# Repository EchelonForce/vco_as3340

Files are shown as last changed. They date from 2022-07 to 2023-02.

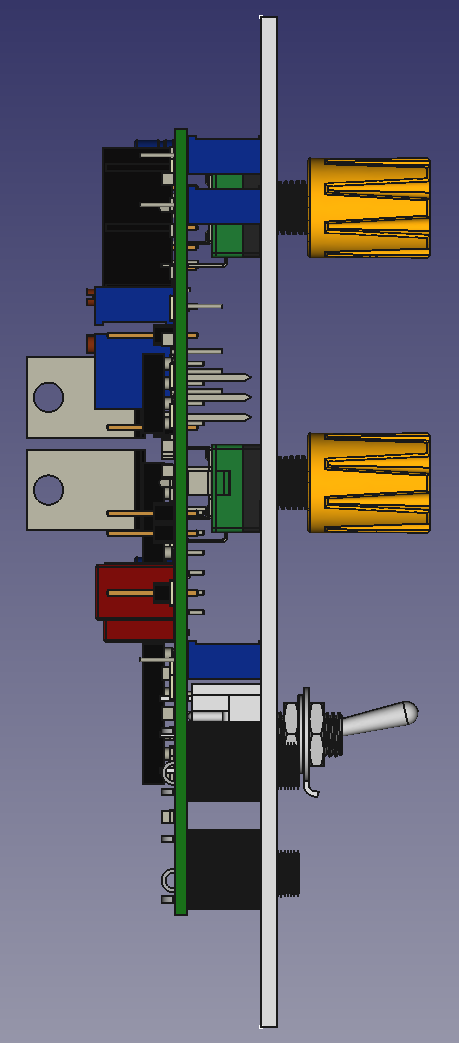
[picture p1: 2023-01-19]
front_panel_v2.1/render3.png

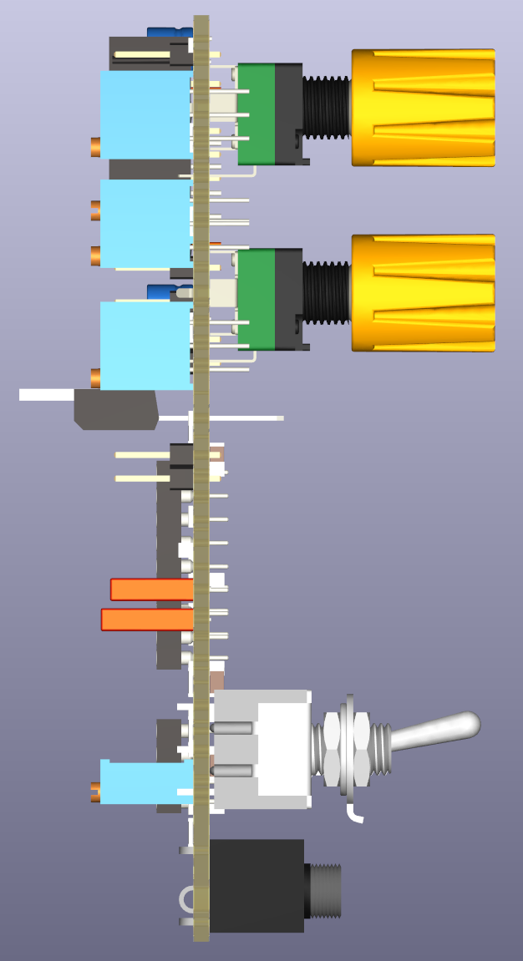
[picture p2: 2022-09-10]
vco_as3340_v1/vco_as3340_v1_render3.png

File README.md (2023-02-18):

# Eurorack VCO AS3340

This is a design for a eurorack VCO using the AS3340 VCO chip.

Full writeup here: https://www.robotdialogs.com/2023/02/eurorack-vco-module-as3340-v21.html
v1. writeup: https://www.robotdialogs.com/2022/09/eurorack-vco-module-as3340.html

This work is licensed under a Creative Commons Attribution-NonCommercial-ShareAlike 4.0 International License. https://creativecommons.org/licenses/by-nc-sa/4.0/

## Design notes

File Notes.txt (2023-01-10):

Issues on v1
 - When making the front panel drawings I noticed the fine tune pot and PWM pot are not equally spaced from the center line. Also the jacks centers are not equidistant from the sides making front panel layout awkward. I made the whole PCB off center relative to the front panel to mitigate this.

 - Fought the output of the pulse wave a lot. There was a lot of ringing on the falling edge. I found some info online https://lookmumnocomputer.discourse.group/t/glitches-or-ringing-on-the-pulse-output-of-the-as3340-and-cem3340/752/5
that suggests using a 10M between the PWM an Pulse pins. I tried that and a few other values but still had issues. I also tried a few small cap values trying to filter the pulse output. Eventually I probed the -5V supply at the chip and found significant ripple in that supply. When I removed the chip (no load) the ripple went away, so I patched in more capacitance at the JP3 jumper (10uF polarized) and that cleaned up the wave considerably. There was still some ring in the pulse output after the buffer that wasn't there pre-buffer (see notes later about scope probe). I removed R6 to help with that. R6 was meant to be a pulldown for the buffer input that I've used in other designs but here it interfered with the R7/R8 voltage divider causing lower than expected output.

- After building 4 of these (intending to test different caps) I have had issues with tuning accross all of them so I pulled them out of the rack and started debugging that. First I started by retrimming everything. I suspect I was impatient after building them because all of them needed adjustment. I powered them all on togeth and let them sit about an hour and then trimmed RZ_TEMP1 again and waited another half hour or so. Then went about the tuning by shorting JP4 and tuning to C6. I found while doing this that tuning one vco against another was easier than tuning to 1046.5 on my scope. The wave forms slide in and out of phase visually on screen and I can get them very close by bringing the slide to a stop but it's fiddely, they never really stop for long. I finished with unshorting and refinding C6 with the 5V CV and C1 with the 0V CV (again tuning with visually helped).

- After all that I let the run for a while and came back to check the pulse wave again and on one it was pretty ringy on the falling edge but only below 5V CV... so I googled again and found this thread
https://modwiggler.com/forum/viewtopic.php?t=231130
That led me to retry a 10M 'hysteresis' resistance between pins 4 and 5, which again didn't work. Strangely if I probed from pin 4 directly the output would be quite a bit better, but a pretty long flank on the falling edge, I guess the scope probe impedance/capacitance was effecting it a lot...On the same thread others mentioned a pull down cap on pin 4 and this improved things significantly. I landed on 100pF after trying large and smaller common values. Unlike the smoothing cap added to the -5V rail earlier, I don't have a nice place to rework this cap to the boards. 

So now there's finally a pretty clean pulse across the 0V-10V range

Current state: 2022-08-23 - See phone photo
 - R10 is 47k
 - 100pF across R10
 - R9 short
 - JP3 10uF polarized cap from -5 to -12 rail. 
 - JP2 short
 - R5 short
 - R6 DNU
 - JP1 short
 - Unit 1 & 2 - red caps
 - Unit 3 - white cap
 - Unit 4 - poly cap
 - R21 & R23 are 5.1k
 - RZ1 18k not 13k

Some other things to investigate.
 - try running on batteries to see if it cleans up frequency meandering? measure first.
 - buy and try higher precision resistors R30, R2,
 - I haven't messed with high freq. track at all yet.
 - Need to do more thorough look at tracking in general from 0-10V.
 - Fine tune knob has a little too much influence on tune, several semi tones... reduce?
   - Increase R3 or reduce range of RFINE_TUNE1
 - Try 5.6k on R21,R23 to reduce component count.

2022-08-28 - Testing Notes
Did a bunch of testing with the frequency counter. 
Completely retuned all four DUTs with frequency counter and mV scale for temp adjust step 1.
The tracking from 0v to 5V looked pretty good using a bench supply for CV and multimeter with mV accuracy. Frequency counter struggled a bit at some frequencies, compared against oscilliscope at lower frequencies.
  Procedure was:
   Powered on for 1hr or more to warm up.
   Readjusted temp1 w/ mV range on multimeter, drifts a bit, got it under a mV.
   Short J4 and get 1046.5 with ref pitch.
   Set Fine Tune knob to center.
   Set Freq knob to 0, full CCW.
   Input CV 5.000V+-0.001
   Use Refind C6 to get 1046.5, this was trickier than with F4 shorted.
   Input CV 0.000V+-0.001
   Use scale adjust to get 32.70+/-0.01 Hz 
   Checked tracking.

 V    Unit   
        1      2       3        4    Ideal
0V    32.7    32.7    32.7    32.7   32.7
1V    65.45   64.9    66.0    66.0   65.41
2V   130.9   130.2   130.7   130.6   130.81
3V   261.9   260.8   261.8   261.4   261.63
4V   523.3   521.6   523.4   522.5   523.25
5V   1047    1045    1049    1046    1046.5

So nearly all within a 1Hz of ideal. 

At this point I checked the weird result the tuner gives me at 1046 with a signal from the frequency gen. I was weird there too and I will investigate that later.

Then I went into trying the DUTs with the midi cv. Unfortunately that also has and issue so the impedance of the oscillators effect it's output. Details in that other note sheet...ugh. 

After some fiddling with the midicv, I thought I had it generating accurate voltages. Unfortunately because the oscillators were tuned with a strong voltage source they didn't behave. All of them need to be offset with the knob :( I want to avoid that, but I guess I have to tune them with the midi source instead??? Kind of confused about this. They seem to work okay with manual tune.

Maybe I just need to redo the circuit and accept the harder tuning method...or maybe is psu voltage differences.
Starting to think a digital oscillator would be so much easier.

2022-09-04
Did some more rigid testing of the AI011 and DUT2. See testing folder notes. 

Schematic Changes v1 to v2:
 - R10 = 47k
 - R9 = 0ohm 
 - New C1 100pF across R10 and R9
 - New C15 10uF polarized cap from -5 to GND. 
 - R6 DNU
 - R21 & R23 changed to 5.1k 
 - RZ1 changed to 18k
 - R26 changed to 100k and new R31 is 100k.
 - New  R32 for 'hysteresis' between PWM and Pulse.
 - Separated grounds on Linear FM and Scale Adj. Circuits for clarity.
 - Added another TL072 (U6) and supporting circuits.
    - This is intended to supply two reference voltages from the 5V source.
    - The idea is to provide Soft Sync (pin 9) with a stable voltage of 1/3*Supply, which is something like 11.3/3.
    - The other REF_PITCH1 is for the Linear FM circuit. Some resistors probably aren't right for this yet, replaced original ref_pitch with this.
  Moved outputs to a tl074 to save some space.
  Removed jp1,2,3 and extra vee stuff, just going to use -5V ref.
  Added second frequency CV jack.

Other 
 - During assembly, short J1 and J2

Sim of virtual ground summing node on CVs
https://tinyurl.com/29nqo2se

https://www.eddybergman.com/2020/01/synthesizer-build-part-18-really-good.html

---------------------------------------------------------------------------------
Issues on v2 PCB:
 - VEE net isn't connected to -5V so the scale adjust circuit isn't powered. Rework short from C10 to RT1.
 - 10pF cap needed on Sawtooth first stage opamp. There was ring in this on the falling edge and this cap helped. (between U4's pins 8/9)
 - Rr1 was changed to 220k from 330k.
 - R4, R33 and R34 should be 100k.
 - C19 should be DNU, it caused oscillation on REF_VOLT_1.
 - Add 10pF on U4B (between pins 6/7) for rising edge of pulse.
 - Add resistors for PWM pot so it's range is limited. (also do fine tune if there's room).
 - Add cal frequencies on silkscreen if there's room.
 - Change supply into REFIND_C6, from 12V to REF_PITCH_1.
 - Change R21 to 10k
 - Change R23 to 0Ohm
 - Change R8 to 110k, lowers pulse out peak to peak.
 
Issues on v2 Front Panel
 - Tried to have holes for the trim pots that are technically on the back of the PCB so they could be mounted on the front, but the holes in the panel are oriented for when the pots are on the back. Need to move them.
 - Trim pot holes could be smaller.
 - Saw wave has rising edge, but it should be falling (rising slope).

Test Notes 2022-12-26:
 - Assembled 2 PCBs.
 - Checked voltage rails +/- 12V, +/- 5V
 - Before adding the AS3340, set the REF_VOLT_1 to 1/3 Vcc = 3.75V
    - I checked REF_VOLT_1 with multimeter (TP3) but that hid the oscillations (almost full peak to peak). Eventually I figure that out with a scope and removed C19 and changed REF_VOLT_1 op-amp resistors for non-unity gain.
 - Add the AS3340.
 - Tried an output and there was no frequency change when the knobs were used...
 - Tried cal step 1 (temp adjust) but the diff between TP1/2 was exactly 0.
 - Debugged this until I figured out the missing VEE net to -5V connection. Fixed with short between C10 and RT1.
 - Checked the other outputs. Sawtooth had bad ring in it the AS3340 output was clean, so I added a 10pF on the first stage opamp feedback which improved it considerably.
 - Did Cal step 1, okay.
 - During Cal step 2 I couldn't get C6 on the output, it was close, so I looked at the new REF_PITCH voltage reference, it was maxing out at ~10V from the opamp, since it can't go any higher I changed Rr1 from 330k to 220k and that was just enough head room. Might need even lower to allow lower input voltages.
 - Checked Fine Tune range. Seems to be +/-2 semi-tones (at 5V on freq CV) which I think is okay.
 - Measured the triangle wave symmetry with scope cursors. Seems perfect at 5V on freq CV. 

Test Notes 2023-01-07:
 - Checked PWM knob range. It goes to 100% Duty too early @ 3.9V. 
  - Need to add a couple resistors inline with the pot to adjust it to the useful range.
 - Recorded some frequency data while adjusting the Vcc from 11.9V up to 12.1V. 
  - The frequency change (starting with 1000Hz at 12V) was 50Hz over the 0.2V range tested. 
    - Also tested a v1.0PCB and the result was similar. This is about 25% per Volt.
  - I think it's due to the REFIND_C6 supply voltage varying.
 - Checked Square wave peak to peak, it's about 11V. And there's a bi of ring on the rising edge.
  - Made R8 = 110k to lower the output closer to 10V.
  - Added a 10pF cap on top of R27 to help the ring. (took photos).
 - Tested the PWM effect on frequency with and without the R32 populated (2.2MOhm and open).
  - No significant difference. Tested 5% increments at a 1000Hz starting point, in both cases, aout 6Hz change over full PWM range.

Test Notes 2023-01-08:
 - Tried to fix the supply voltage into REFIND_C6. cut the 12V trace and wired it to TP4 (REF_PITCH1).
  - Checked REF_PITCH1 with scope after rework to make sure it was stable still.
  - After this tried several Vcc voltages and it's much improved, At 1000Hz @ 12V, 998 @ 12.25V and 1004 @ 11.75V. So about 6Hz over 0.5V. This is about 1.2% per Volt. That's way better than yesterday's test w/o this. Through test REF_PITCH1 was rock solid 9.727V (set from cal steps).

Old Todos:
 - Test CV to freq scaling more throughly.
    - Done.
 - Test freq/pwm shift and try the 'hysteresis' resistor R32.
    - Done.
 - Test with different supply voltages to see if the behavior is better.
    - Done. It's about the same as v1.0 until I reworked REFIND_C6 supply.

 - Tested the HF Track adjustment. At 10V CV the pot couldn't reach an adequate setting for 33488Hz.
 - Decided to measure the voltage (and therefor current) of the HF Track pin. At 10V CV, the HF pin over the 20200k combined resistance, the voltage was 1.331V (also tested other CVs). So there's about 65uA out of the HF pin. Instead of risk a bunch of other issues, swapped the resistors but kept the overall resistance nearly the same.
  - Removed both 5.1k R21/R23. R21 was changed to 10k, R23 was shorted. This put the trim pot in the area need to trim out the tracking error at 10V CV.
  - Re-tested tracking from 0 to 10V CV. All good: https://docs.google.com/spreadsheets/d/1qfa5OgiflcCrpyueND8rxWKN7h0p5OLnycMwUe4vgko/edit?usp=sharing
 - Did all reworks to DUT2 and calibrated it. Seems okay.

Test Notes 2023-01-09:
 - Checked Sync input. Seems okay on hard sync. Requires hard edges like VCO pulse, soft edges don't work. 
    - Switch is not really useful with REF_VOLT and JP5. Added JP1 so that switch can function as a sync enable/disable.
 - Updated PCB and Schematic with all changes in redlined pdf of v2.

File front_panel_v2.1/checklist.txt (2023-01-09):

Kicad:
Open the PCB and export as .step.

FreeCAD:
Copy the template.
Set hp and pcb size in dims spreadsheet
Import .step of pcb from kicad.
Align pcb model with pcb in sketch.
Add holes for jacks etc.
Switch to tech draw workbench. 
Select 'TOP' view of part.
Add part to drawing.
Export as ...no_engraving.dxf (with only part shown, no dims).

Inkcape:
Open .svg template in Inkscape.
Pamel Layer:
  Import the .dxf of the the panel on a layer.
  Change the line stroke to .1 mm
  Scale the .dxf to the nominal panel size, importing screws this up.
  Adjust the page size to the nominal panel size.
Logo Layer:
  Import the Logo\BLEEP_BLOOP_LOGO.svg
  Change the line stroke to .1 mm
Text Layer:
  Add text converting to HersheyText.
   - RobotDialogs
   - Module Name
   - Jack and Pot Labels
   - Voltage Labels
  Change the line stroke to .1 mm
  Remember clearance for nuts/knobs.
Other Layers:
 - As needed.
Save as ...engraving.dxf (AutoCAD DXF R14).

Optional, to double check/render.
FreeCAD:
 - Switch to Draft workbench, turn off the grid (last button on toolbar 'Toggle Draft Grid').
 - Import the engraving dxf.
 - Select all the bits that were imported and select 'Convert draft object to sketch'.
 - Delete the draft objects.
 - Move the sketch +2mm in Z.

Final Checks:
Check text positions, remember clearance for nuts/knobs.
Check that jack/knob names match PCB.
Check for Logo
Check for Voltage labels
Check for missing LED hole.

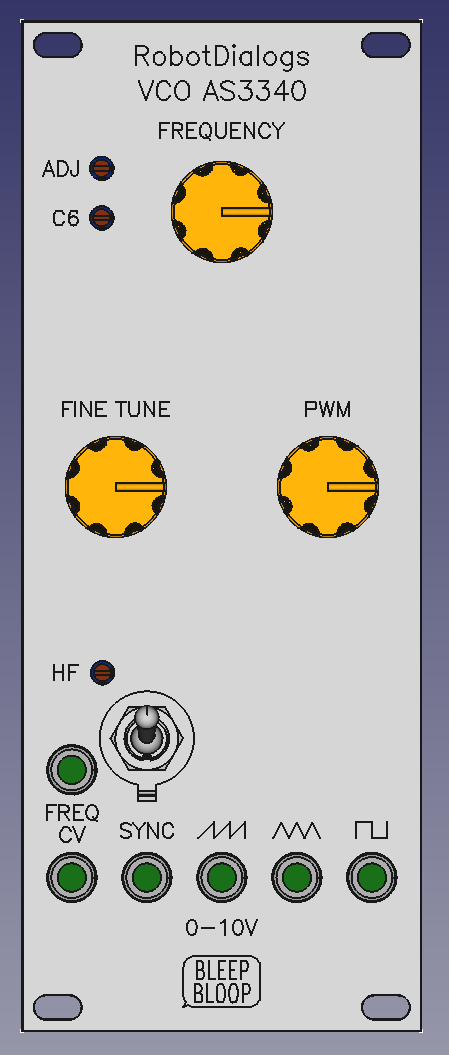
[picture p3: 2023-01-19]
front_panel_v2.1/render1.png

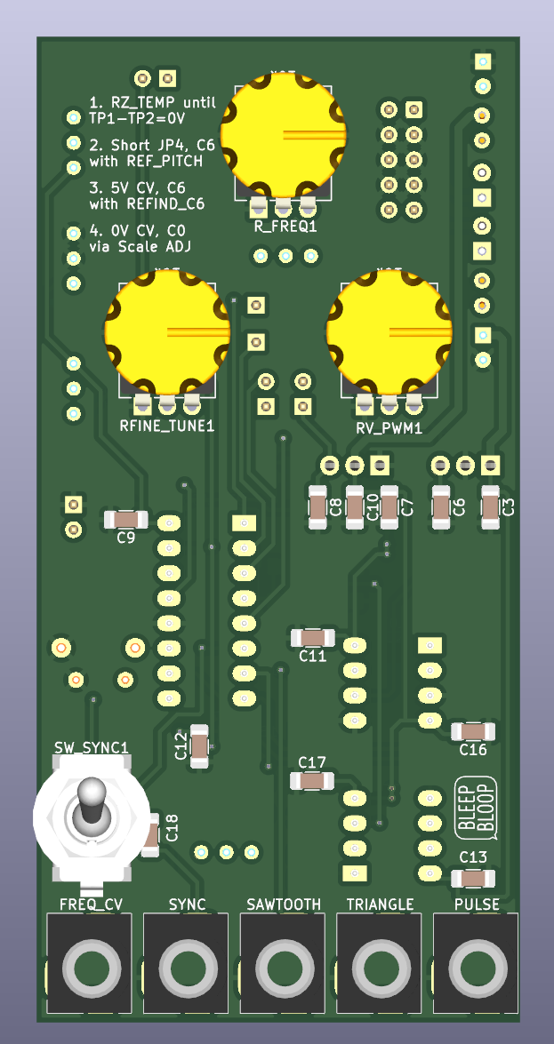
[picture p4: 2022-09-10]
vco_as3340_v1/vco_as3340_v1_render1.png

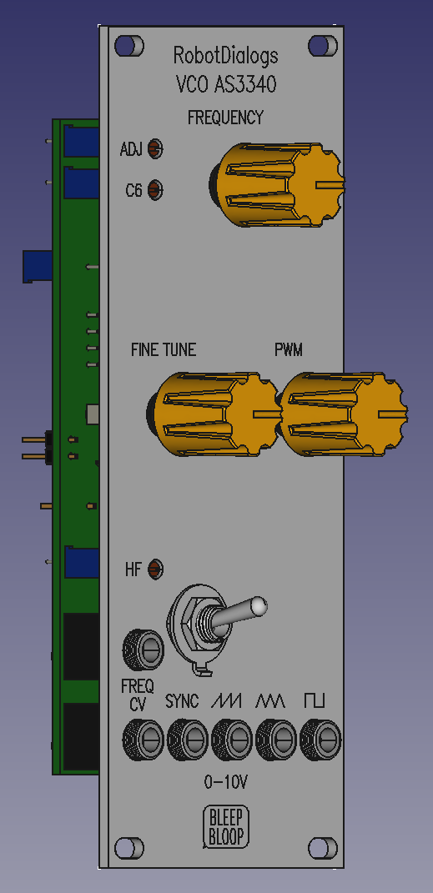
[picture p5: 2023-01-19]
front_panel_v2.1/render2.png

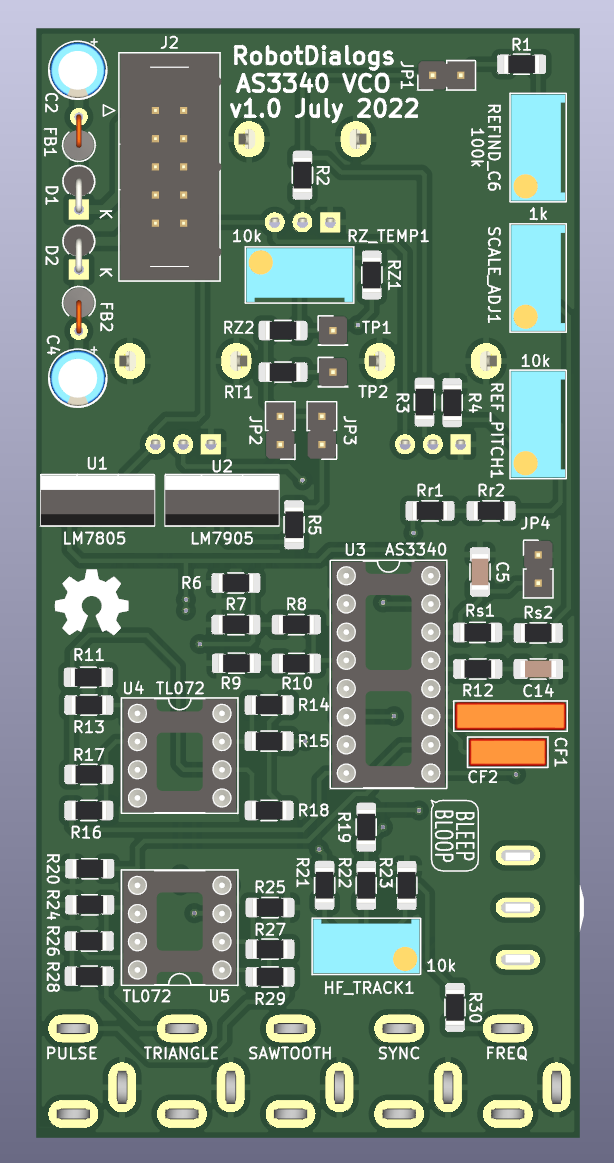
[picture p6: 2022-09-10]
vco_as3340_v1/vco_as3340_v1_render2.png

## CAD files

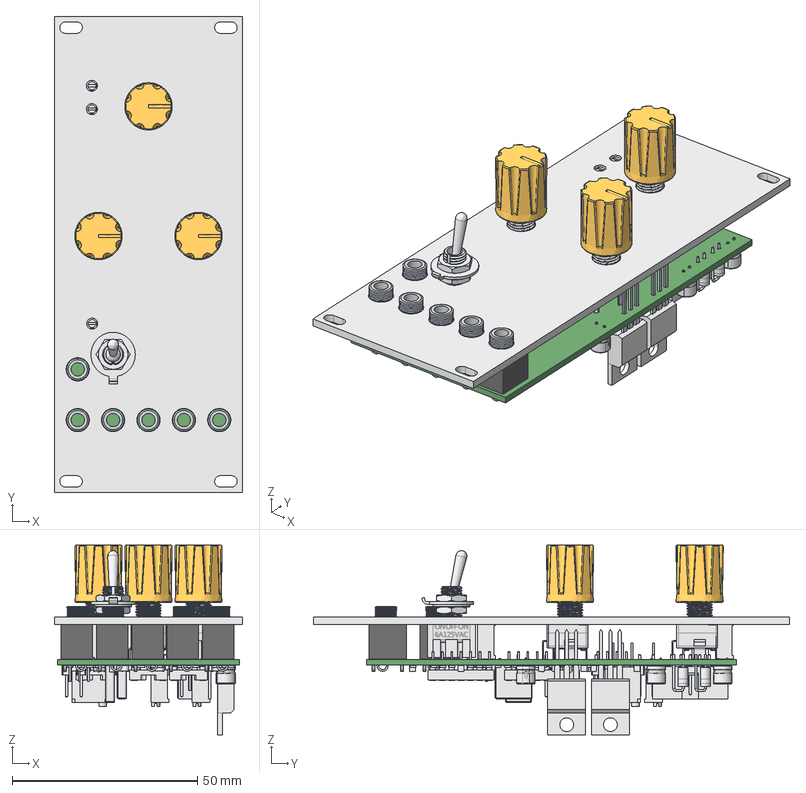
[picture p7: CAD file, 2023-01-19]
front_panel_v2.1/vco_as3340_v2.1_front_panel_v2.1.FCStd
50.8 x 128.5 x 51.3 mm
vco_as3340_v1 PCB

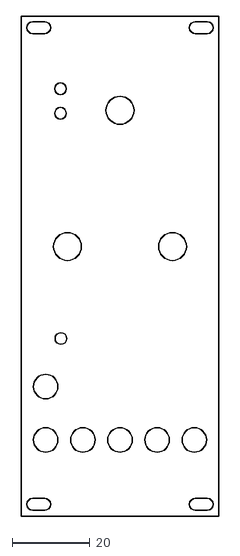
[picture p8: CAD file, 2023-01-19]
front_panel_v2.1/vco_as3340_v2.1_front_panel_v2.1_no_engraving.dxf
50.8 x 128.5

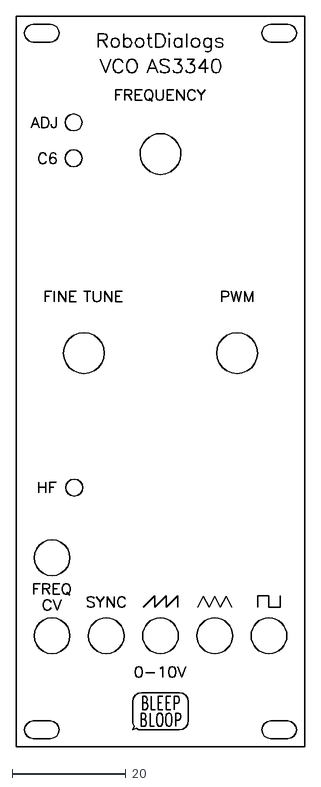
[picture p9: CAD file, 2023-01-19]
front_panel_v2.1/vco_as3340_v2.1_front_panel_v2.1_engraving.dxf
50.7 x 128.4

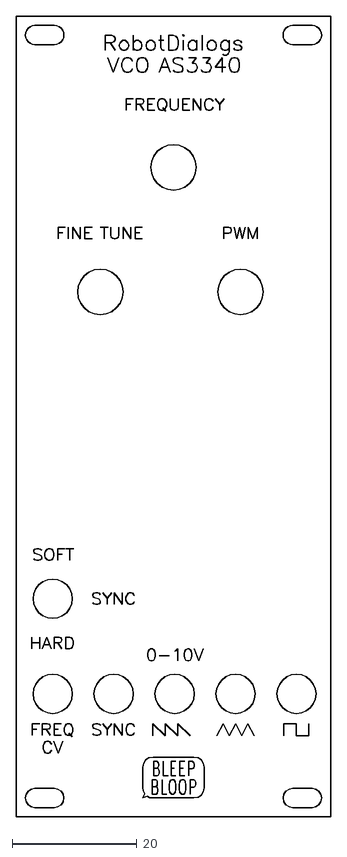
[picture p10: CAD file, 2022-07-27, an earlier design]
front_panel_v1/vco_as3340_front_panel_engraving_v1.1.dxf
50.5 x 128.5

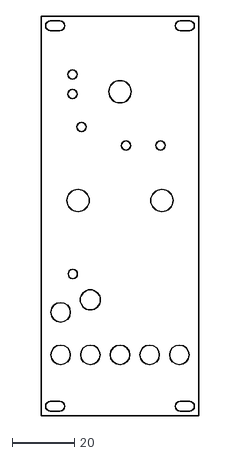
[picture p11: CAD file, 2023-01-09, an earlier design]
front_panel_v2/vco_as3340_v2_front_panel_v2_no_engraving.dxf
50.8 x 128.5

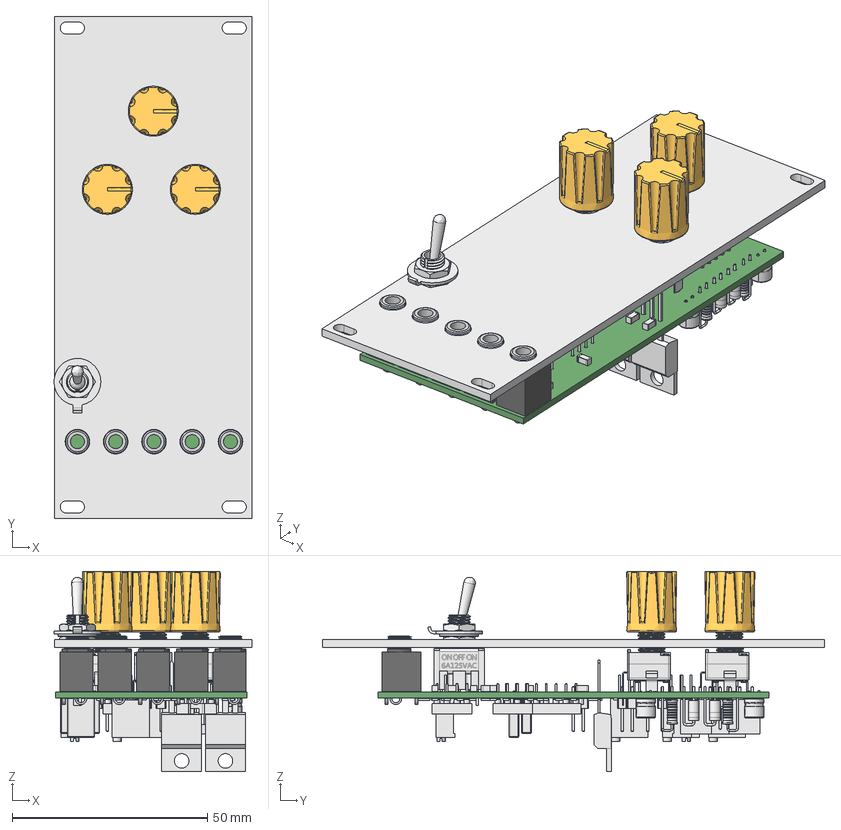
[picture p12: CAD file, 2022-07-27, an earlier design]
front_panel_v1/vco_as3340_front_panel_v1.1.FCStd
50.7 x 128.5 x 51.3 mm
vco_as3340_v1 PCB

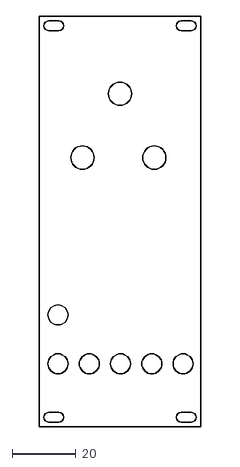
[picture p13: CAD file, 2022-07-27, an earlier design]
front_panel_v1/vco_as3340_front_panel_v1_no_engraving.dxf
50.5 x 128.5

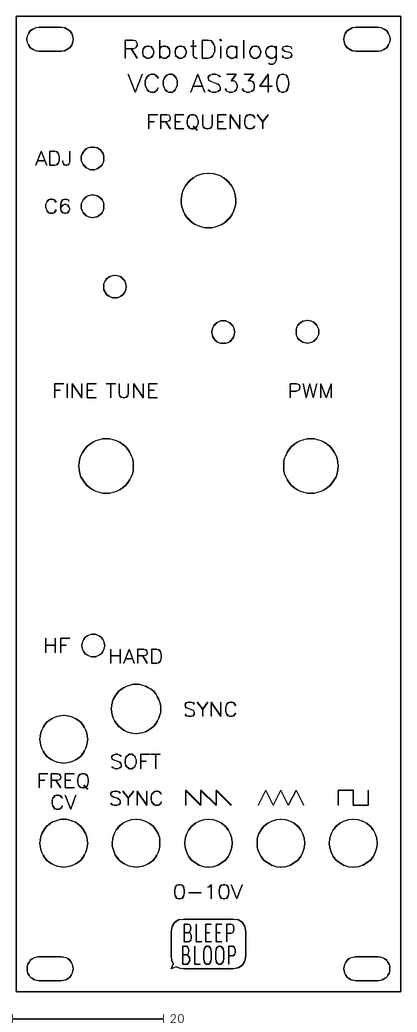
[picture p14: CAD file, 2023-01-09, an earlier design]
front_panel_v2/vco_as3340_v2_front_panel_v2_engraving.dxf
50.7 x 128.4

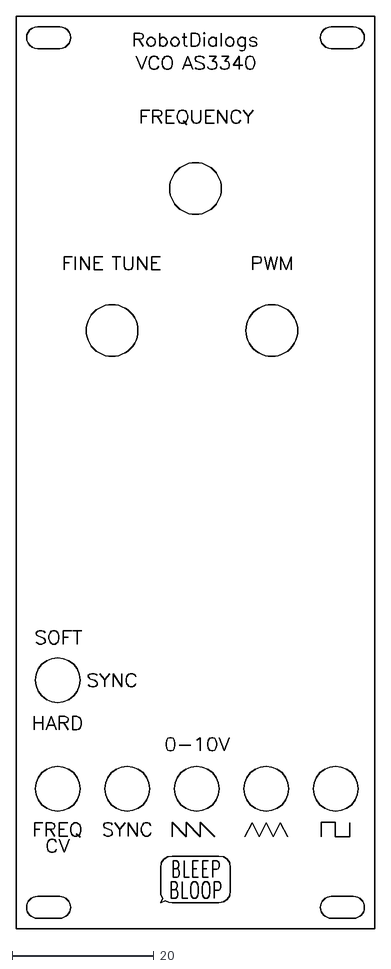
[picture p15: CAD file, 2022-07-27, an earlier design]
front_panel_v1/vco_as3340_front_panel_v1_engraving.dxf
50.5 x 128.5

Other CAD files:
front_panel_v2/vco_as3340_v2_front_panel_v2.FCStd
front_panel_v1/vco_as3340_front_panel_v1.FCStd

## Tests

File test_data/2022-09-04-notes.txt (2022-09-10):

data was collected from a rigol dg1062 which seems to not be very robust for screen shots so there are duplicate files on disk?! 
whatever. 
most of the data is there and I used a paper record from a Trio FC756 too:

AI011 - Wanted to compared to another design.
    trio freq    CV     freq_rigol
0        999   4.999     998.8
1       1001            1000.3
2       1001            1000.7
3       1000            1000.9
4       1001   4.996    1001.2        - 
5       1001            1001.0
6       1001            1000.9
7       1001            1000.7
8       1000            1000.7?duplicate
9       1001   4.955    1000.4
10      1001            1000.4 stdev after stabilized is ~150mHz

DUT#2
    trio freq    CV     freq_rigol
0       998     4.994    999.0
1      1000     4.993   1000.3
2      1001     4.993   1000.6
3      1001     4.993   1001.0
4      1001     4.993   1001.2
5      1002     4.992   1001.4
6      1001     4.992   1001.2
7      1001     4.992   1001.4
8      1002     4.992   1001.5
9      1002     4.992   1001.6
10     1001     4.992   1001.5
11     1002     4.991   1001.5
12     1002     4.991   1001.5
13     1001     4.991   1001.3 stdev after stabilized is ~70mHz       

Because the CV was falling this might be a little skewed because that would counter the drift upward.
So bloody hard to test this.

While I had DUT2 warmed up, I also measured the frequency drift against the PWM, for this I just read the duty and freq off the rigol. The trio struggled at the lowest duty.

PWM Duty +/-1%   Frequency +/-0.1Hz
~ 1%             1009.5
  5%             1009.2
 10%             1008.8
 15%             1008.4
 25%             1007.9
 30%             1007.3
 35%             1006.7
 40%             1006.3
 45%             1005.9
 50%             1005.3
 55%             1004.6
 60%             1004.3
 65%             1003.7
 70%             1003.3
 75%             1002.6
 80%             1002.2
 85%             1001.5
 90%             1000.9
 95%             1000.3
~98%              999.6 - The falling edge prevents any larger duty.

So there's 10hz drift (~1%) over the range of the pwm input.

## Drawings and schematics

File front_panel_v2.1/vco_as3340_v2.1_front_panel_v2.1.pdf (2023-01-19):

1

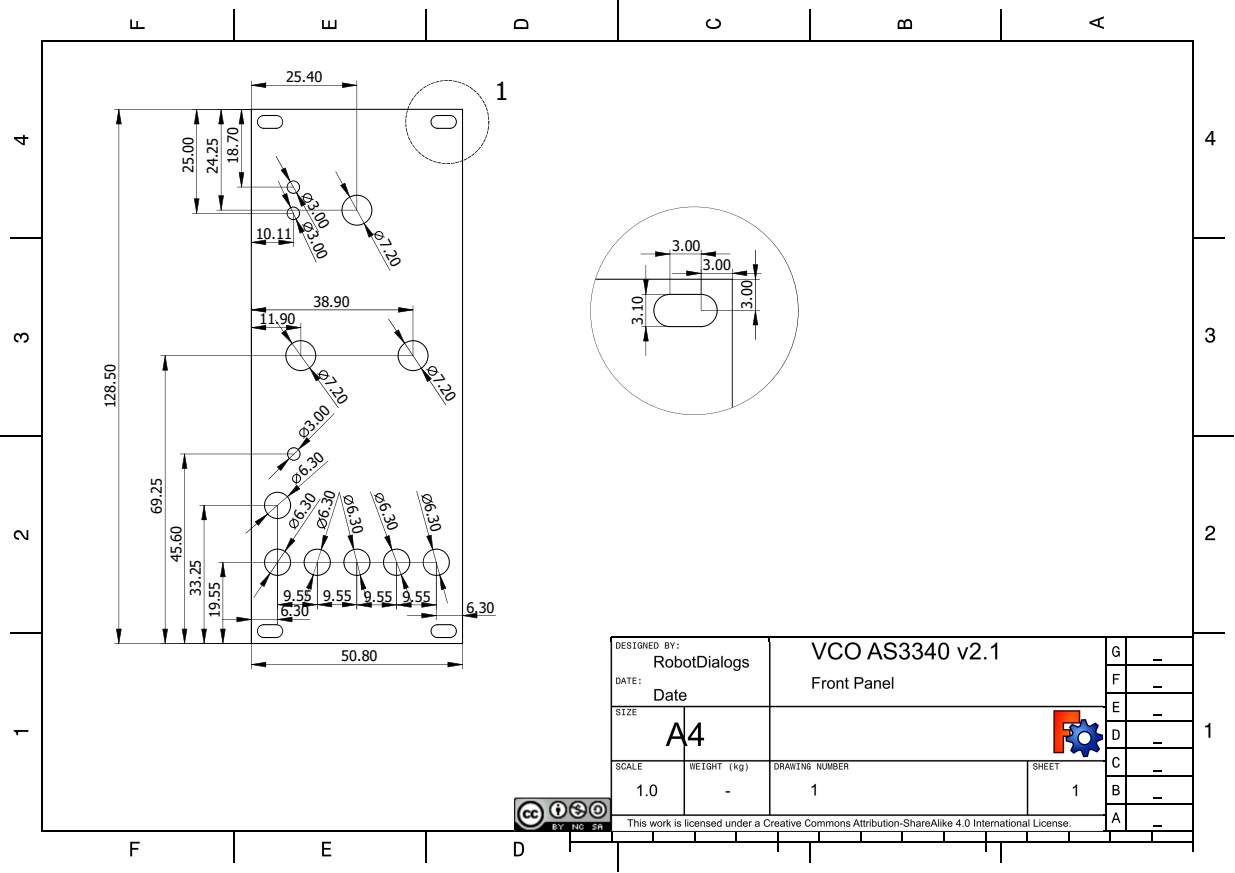
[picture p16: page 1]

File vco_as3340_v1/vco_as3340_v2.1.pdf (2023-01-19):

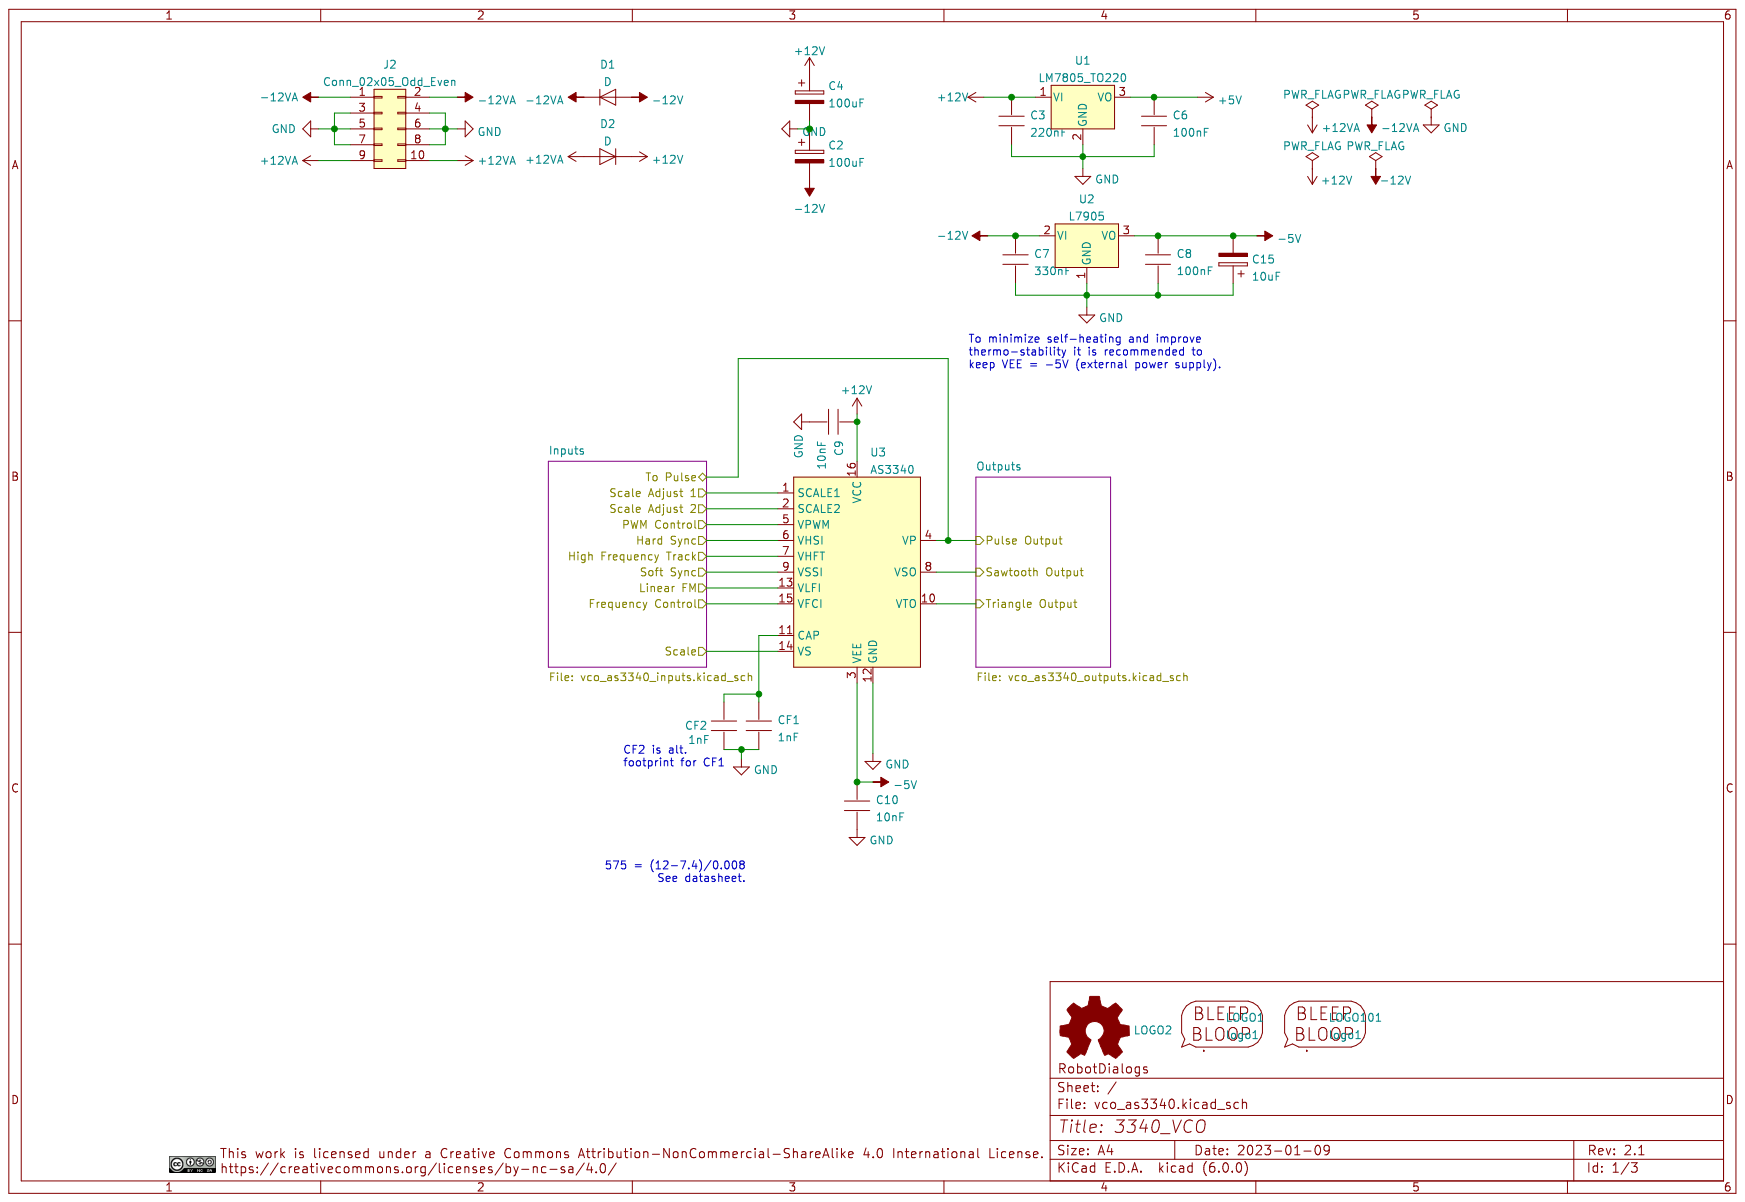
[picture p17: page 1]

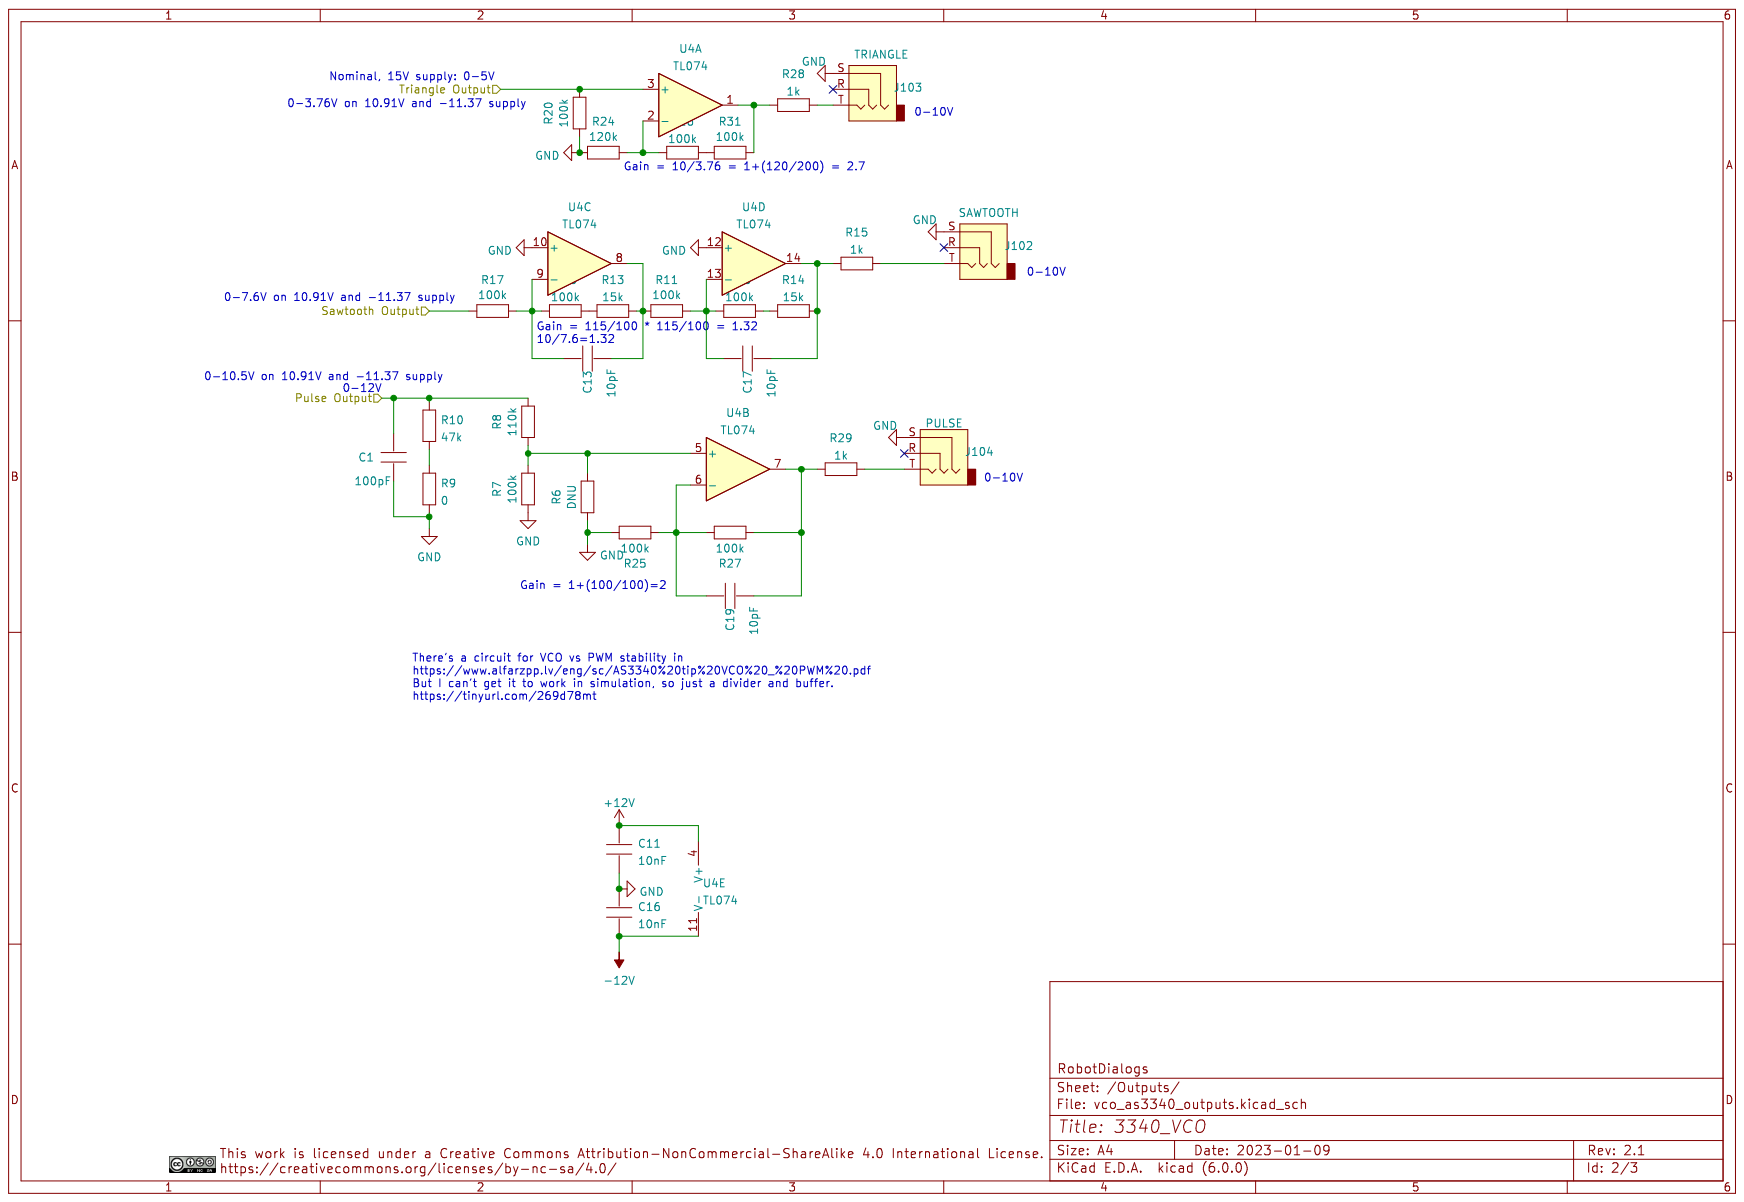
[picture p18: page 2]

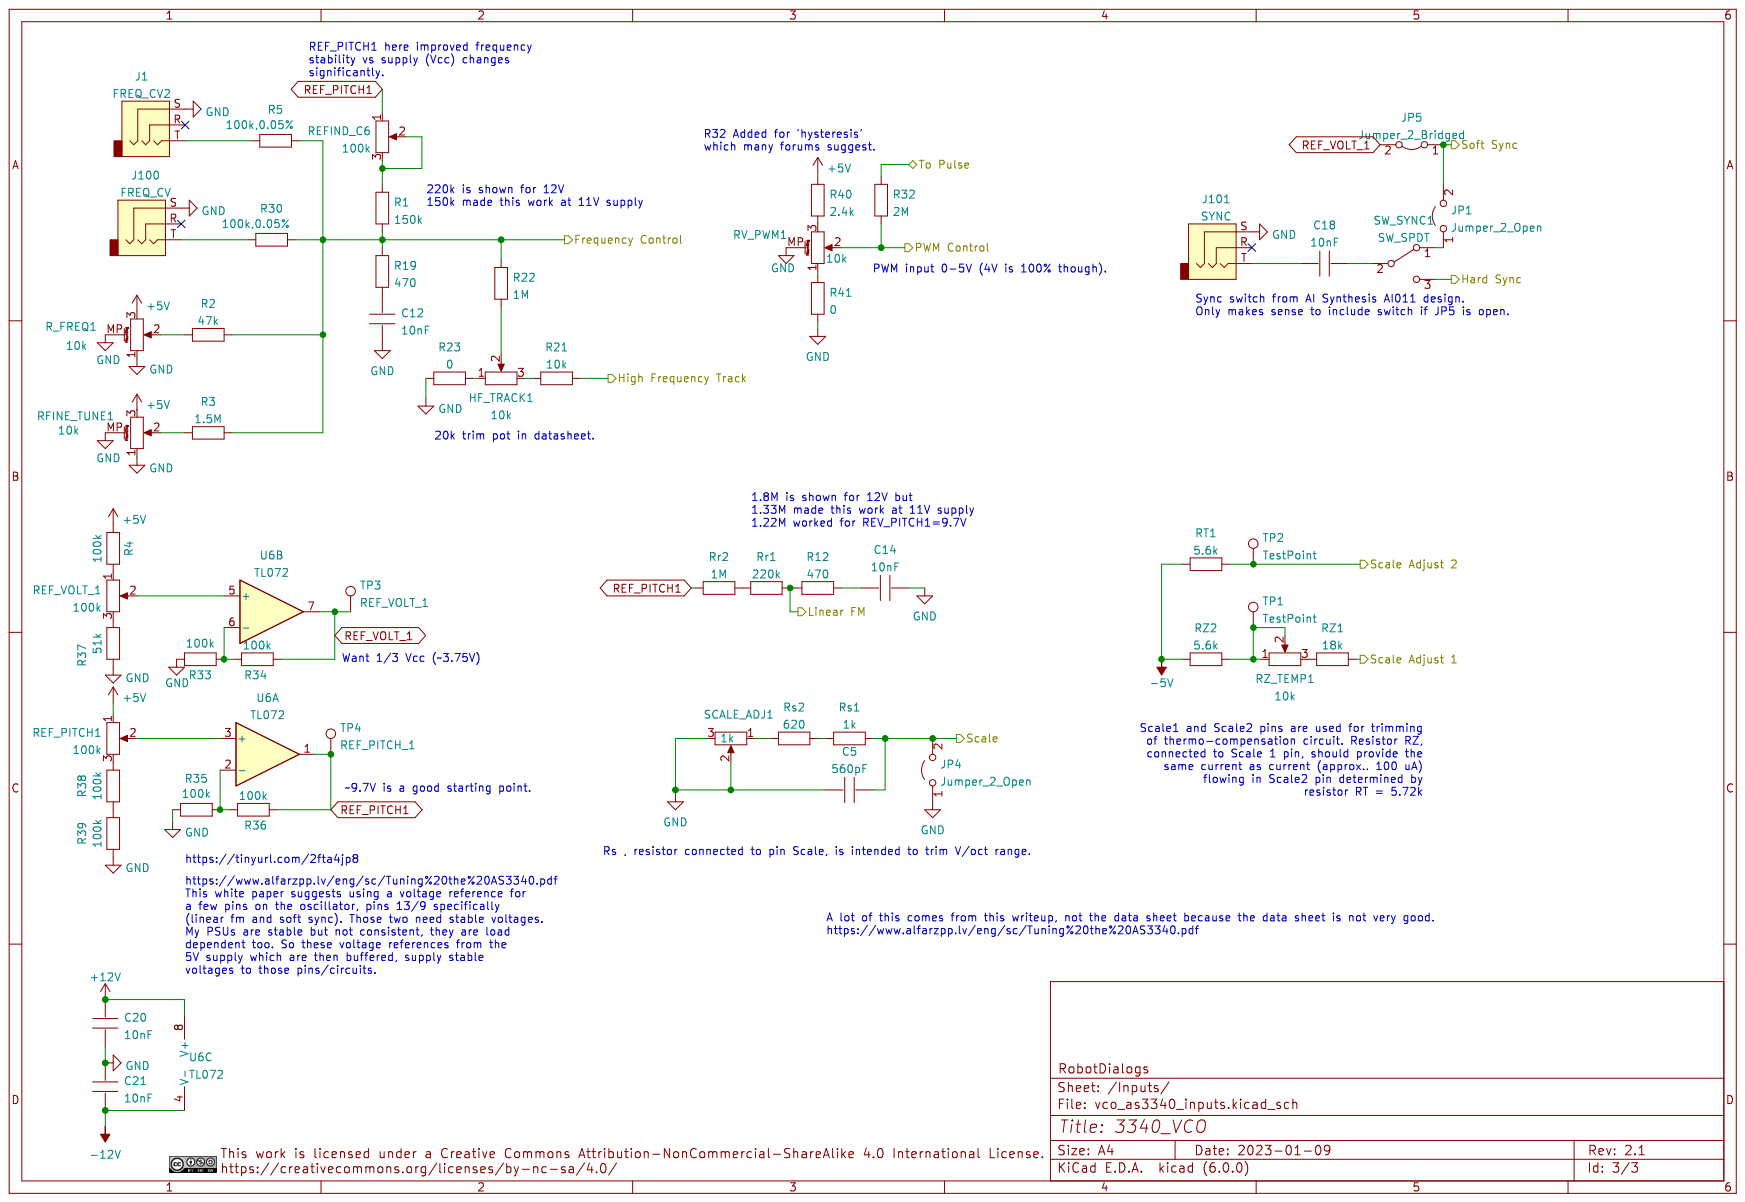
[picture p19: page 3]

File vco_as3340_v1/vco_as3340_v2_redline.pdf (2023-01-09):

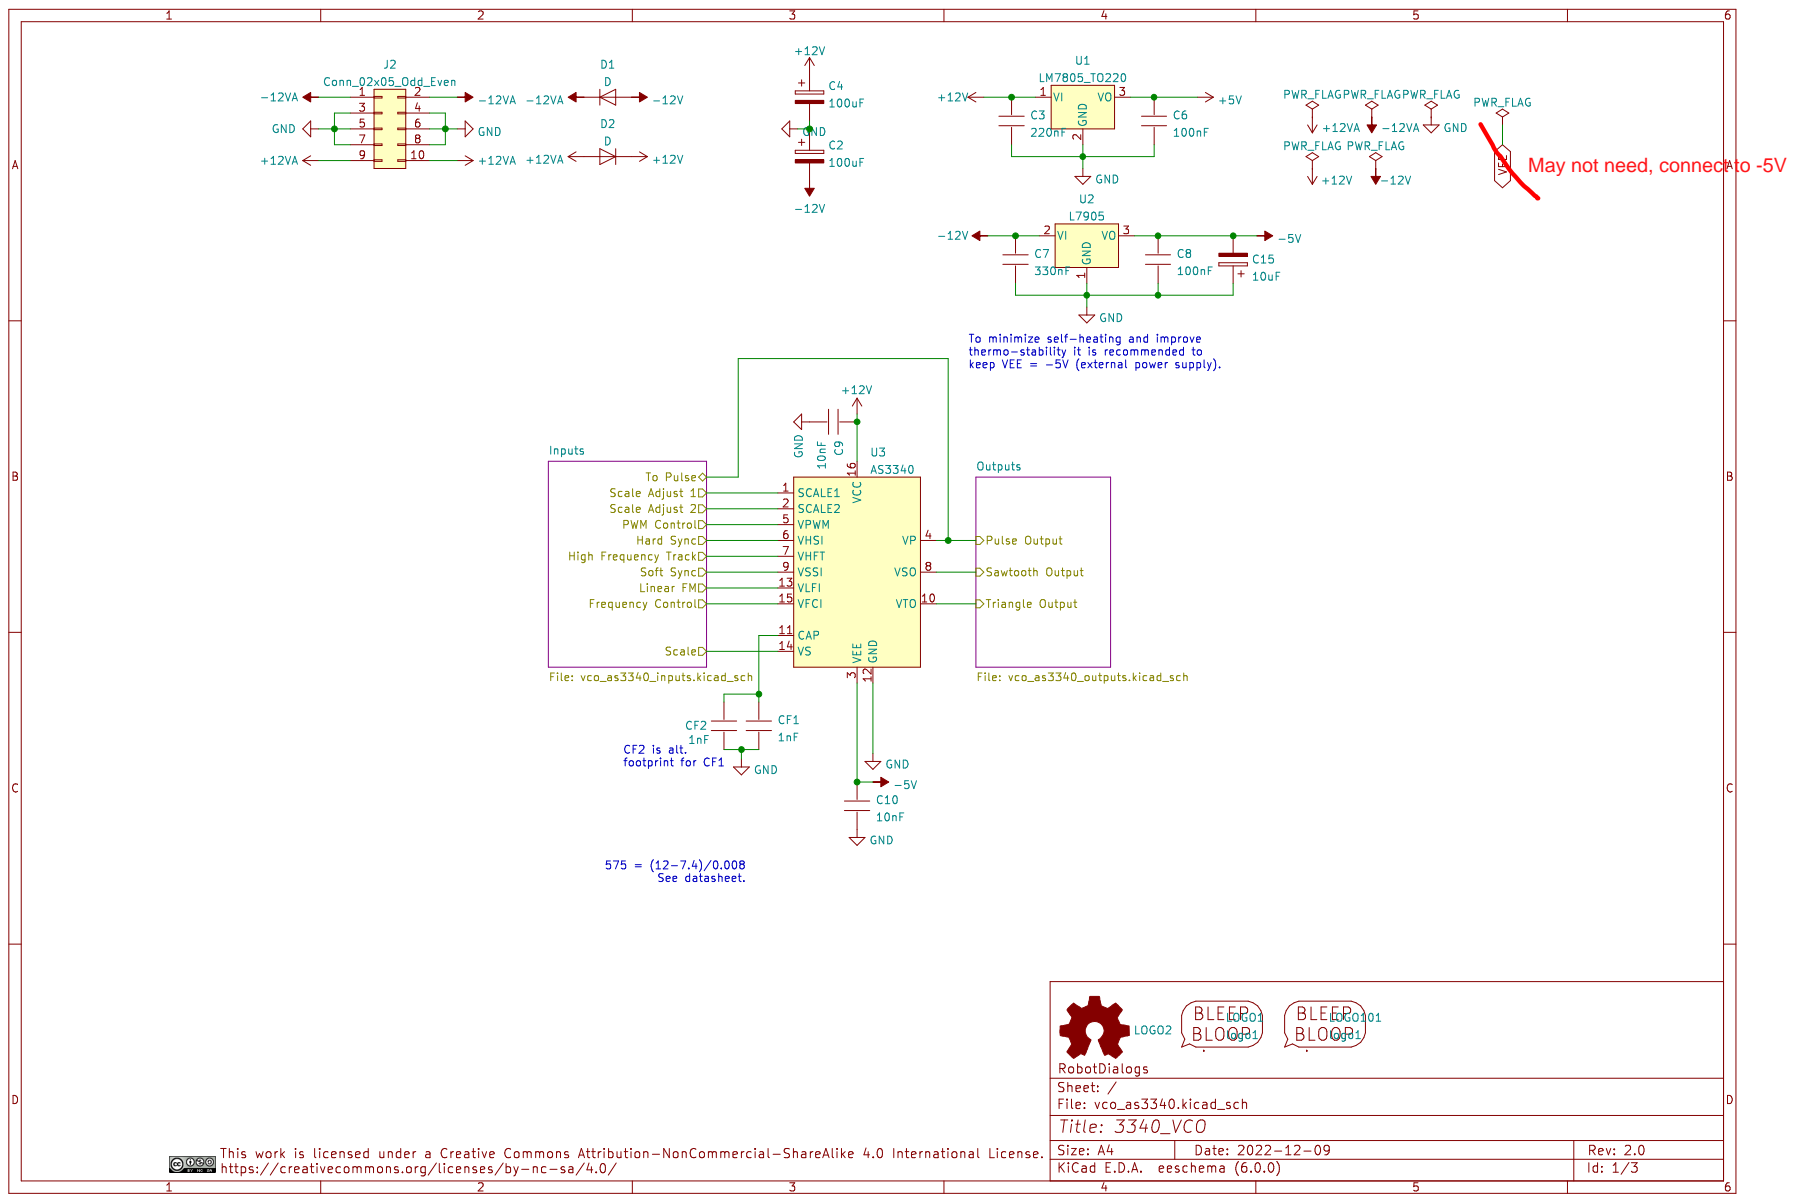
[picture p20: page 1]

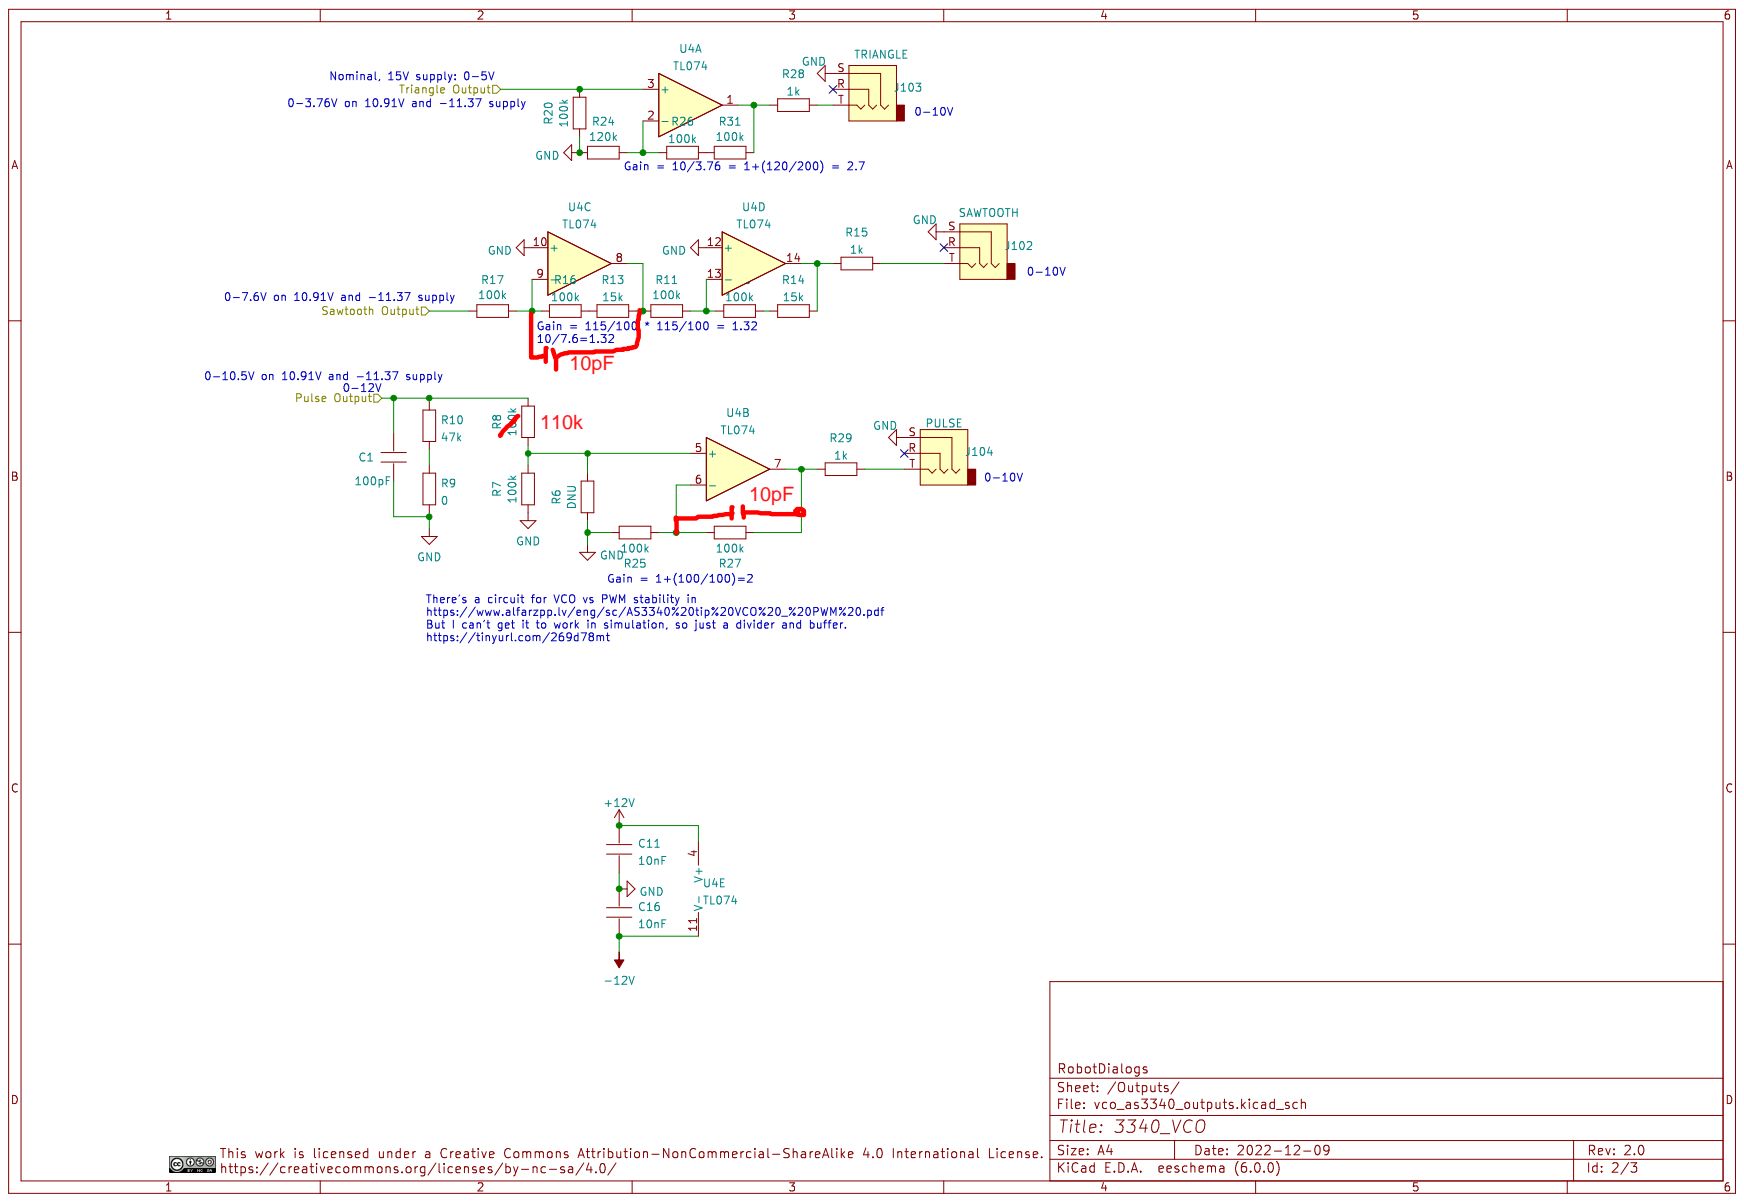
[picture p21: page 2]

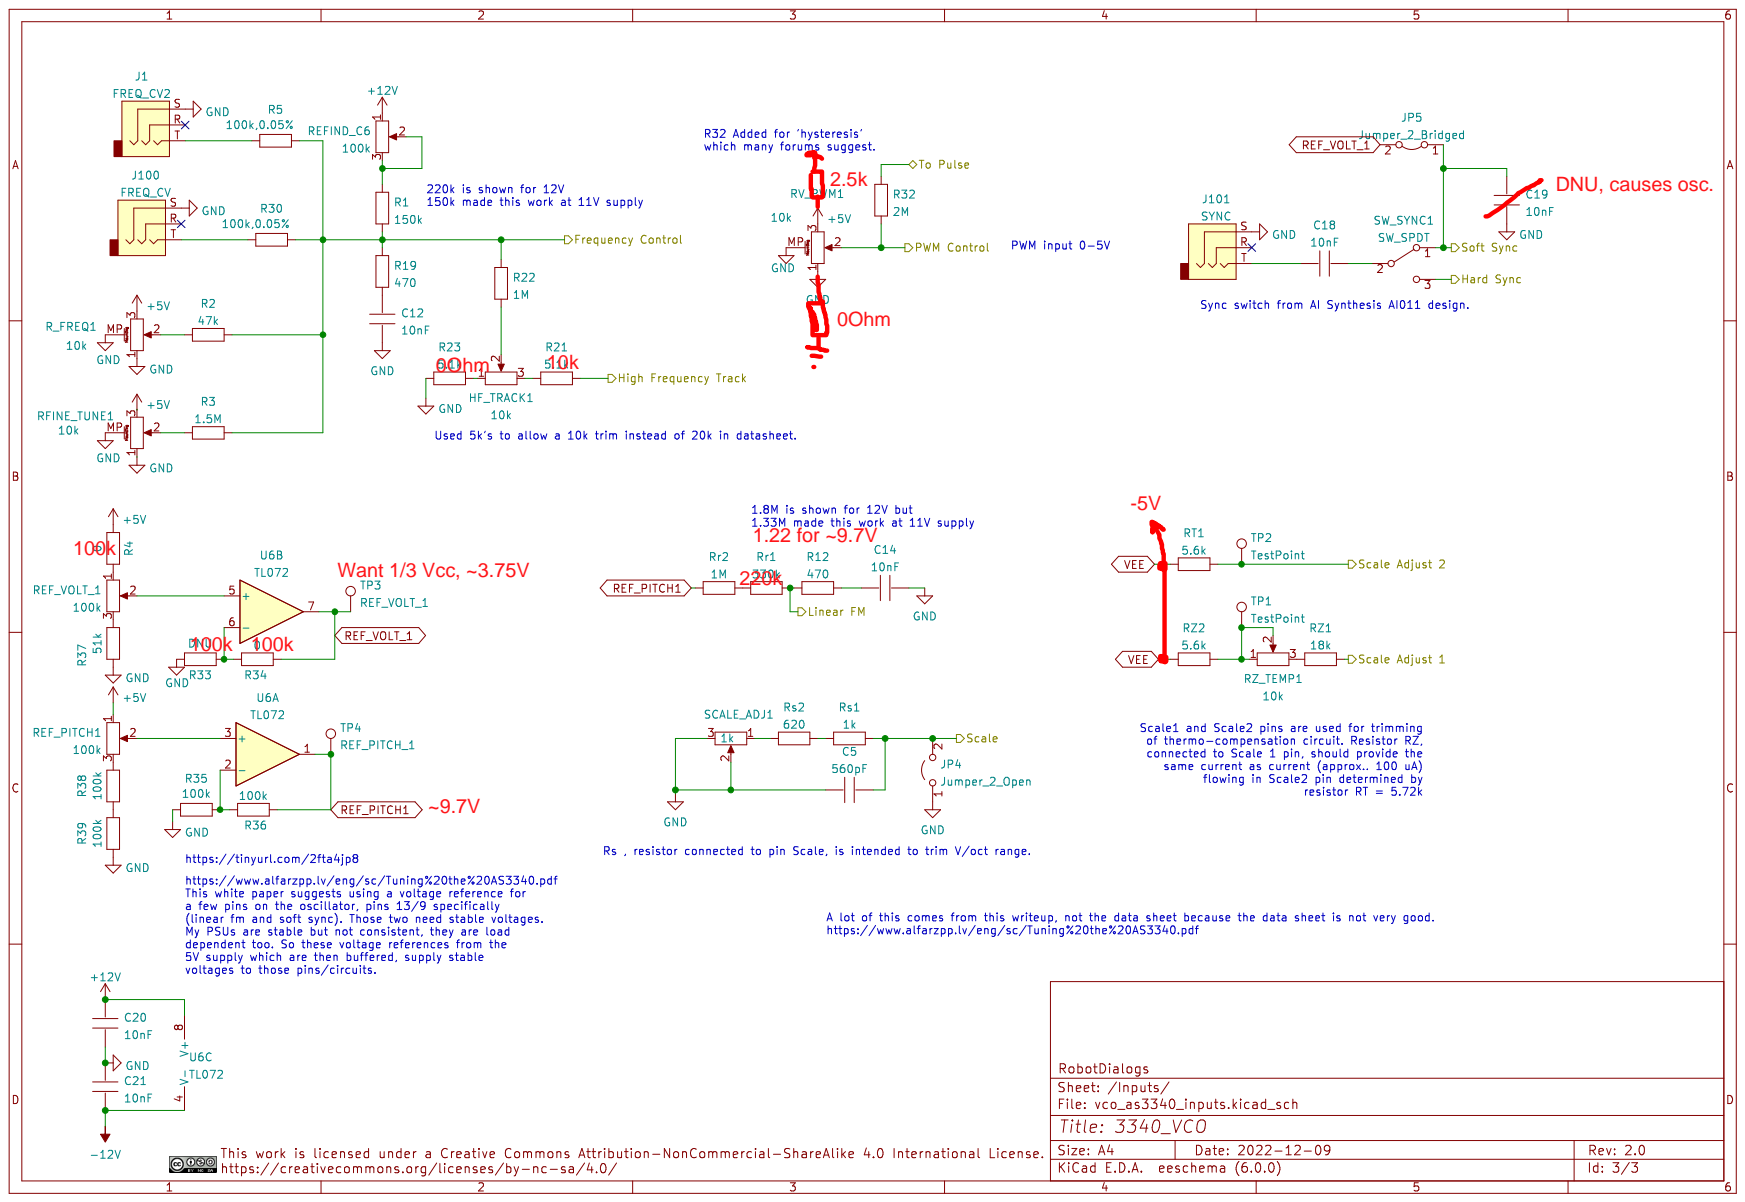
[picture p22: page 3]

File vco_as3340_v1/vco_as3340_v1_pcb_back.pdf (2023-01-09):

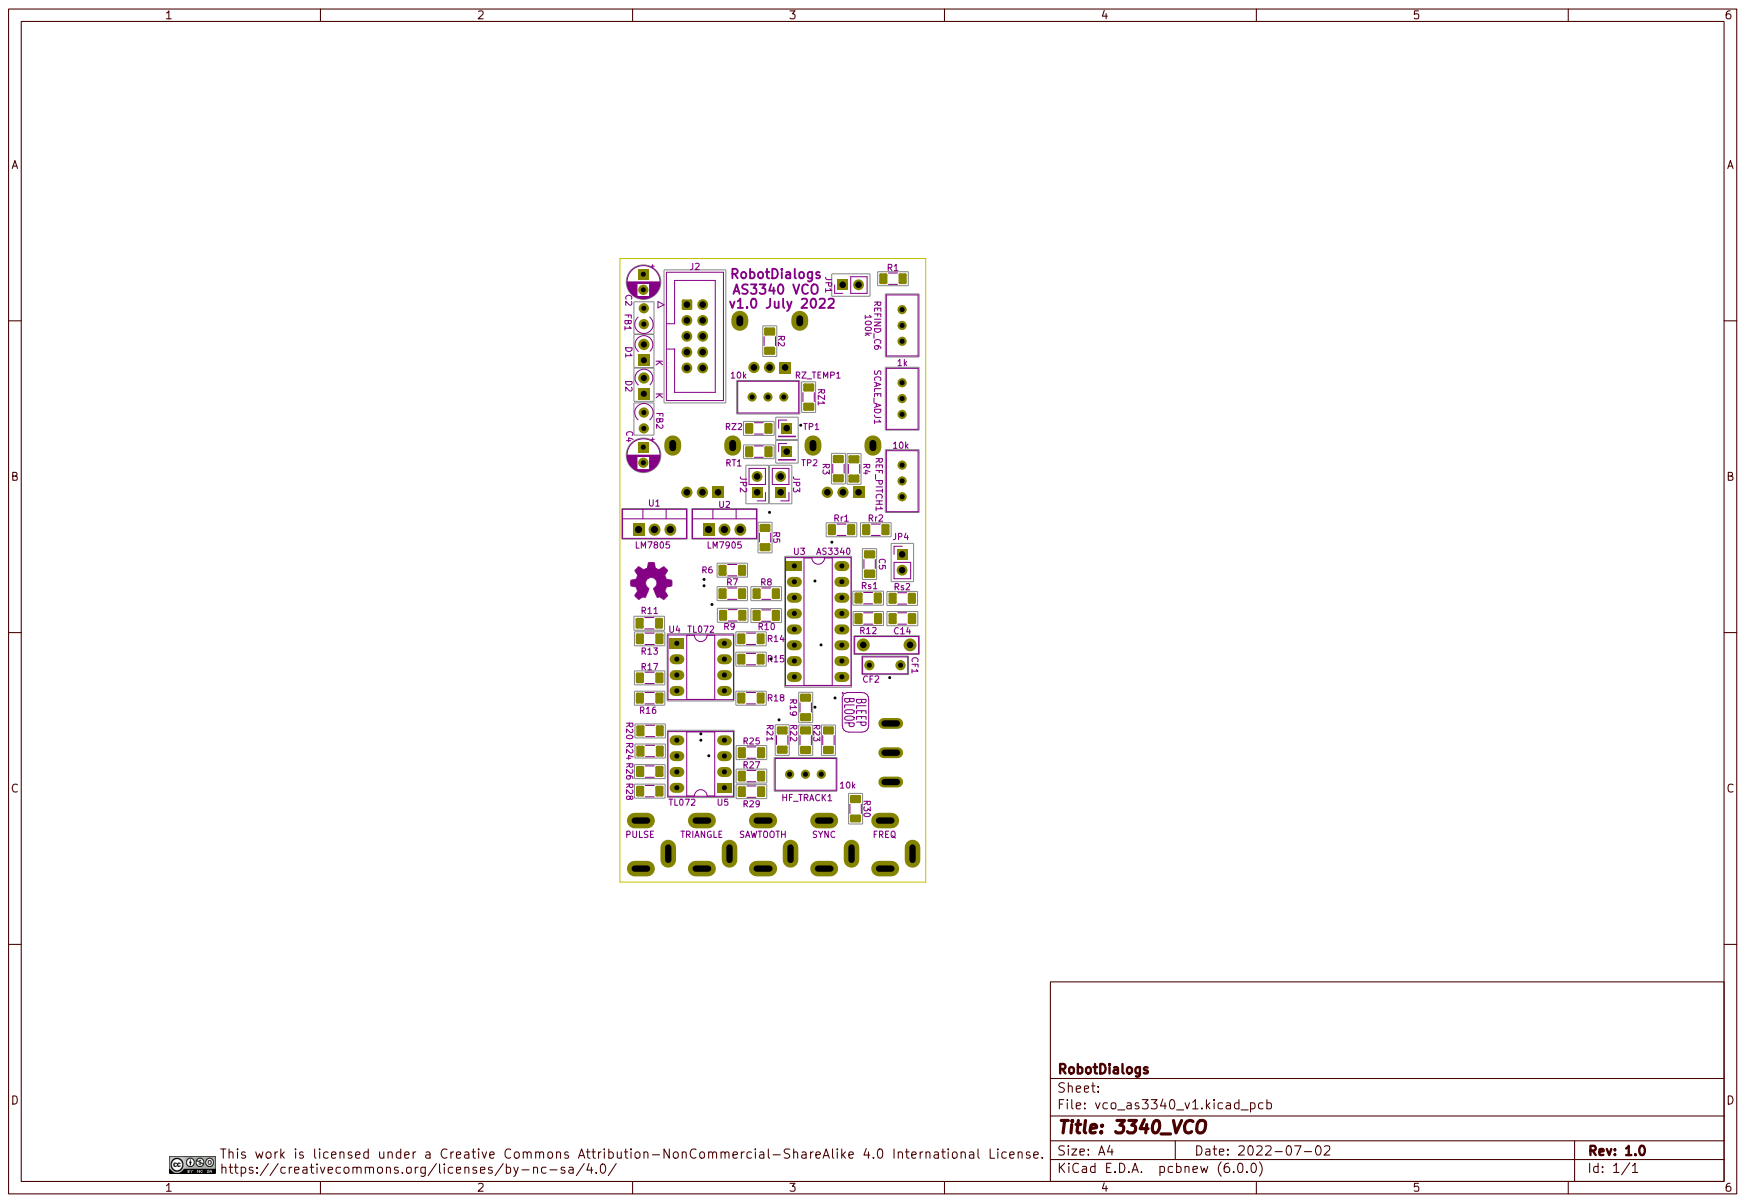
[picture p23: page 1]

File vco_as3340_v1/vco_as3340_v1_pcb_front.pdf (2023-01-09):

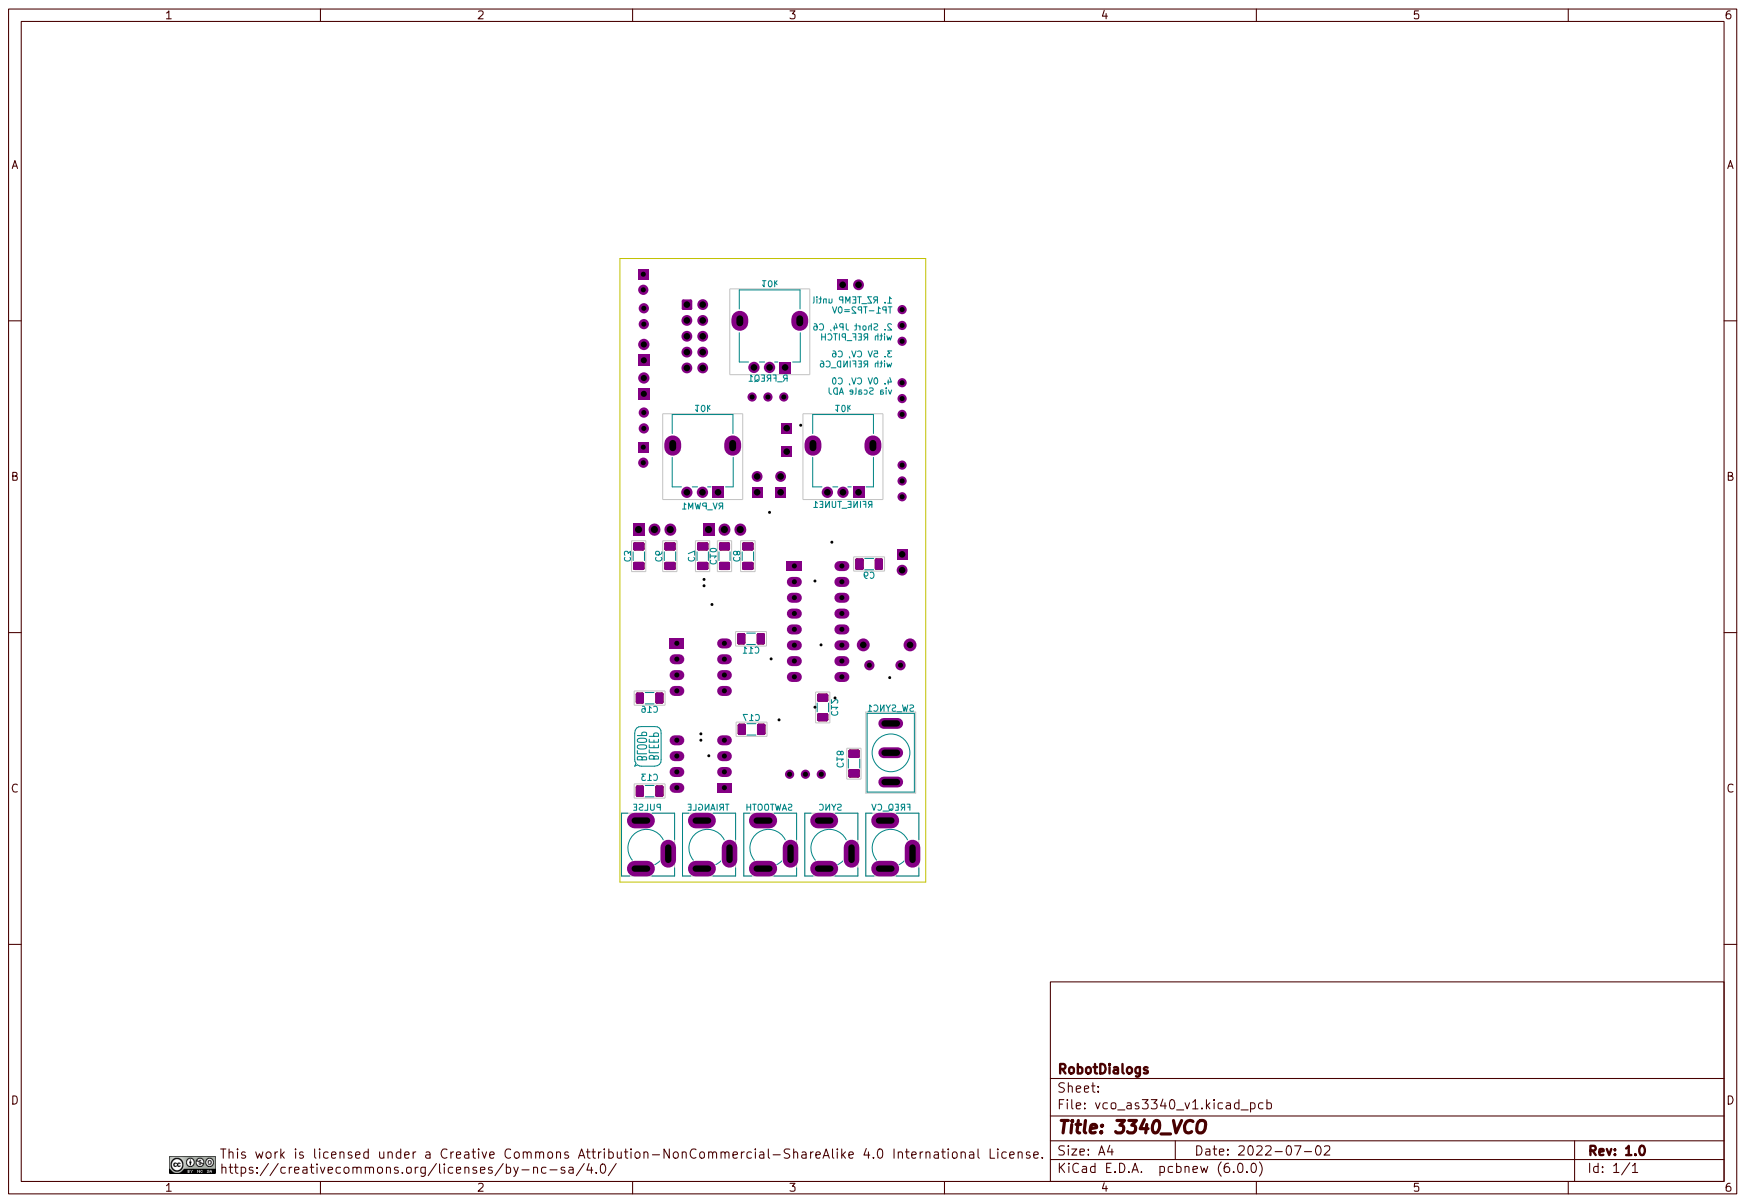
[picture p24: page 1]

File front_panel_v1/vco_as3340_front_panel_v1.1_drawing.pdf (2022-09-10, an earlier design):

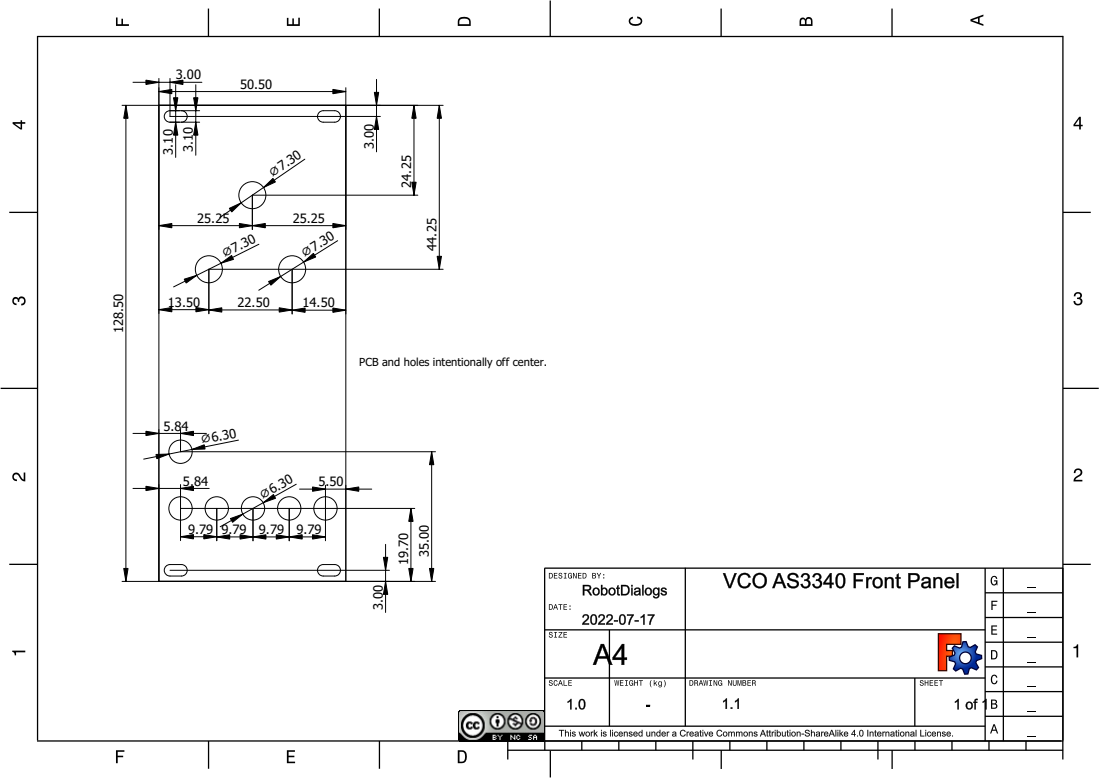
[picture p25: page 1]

PCB and holes intentionally off center.

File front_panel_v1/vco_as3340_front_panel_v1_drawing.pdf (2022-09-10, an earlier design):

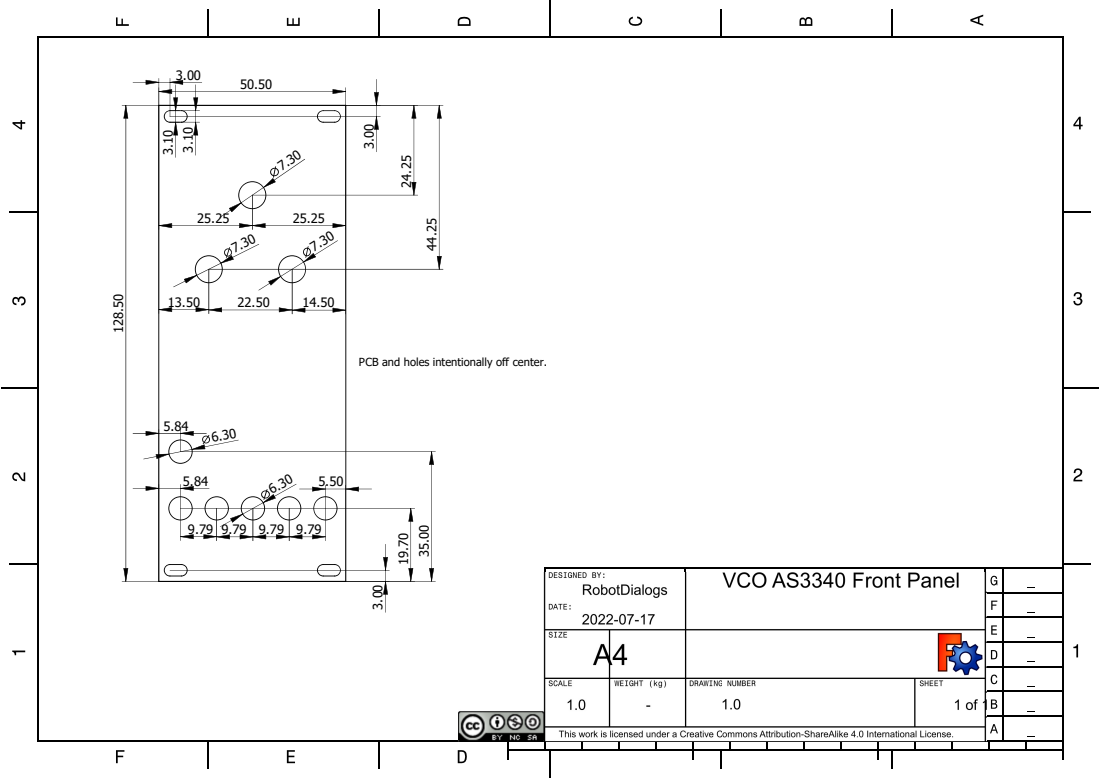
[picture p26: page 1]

PCB and holes intentionally off center.

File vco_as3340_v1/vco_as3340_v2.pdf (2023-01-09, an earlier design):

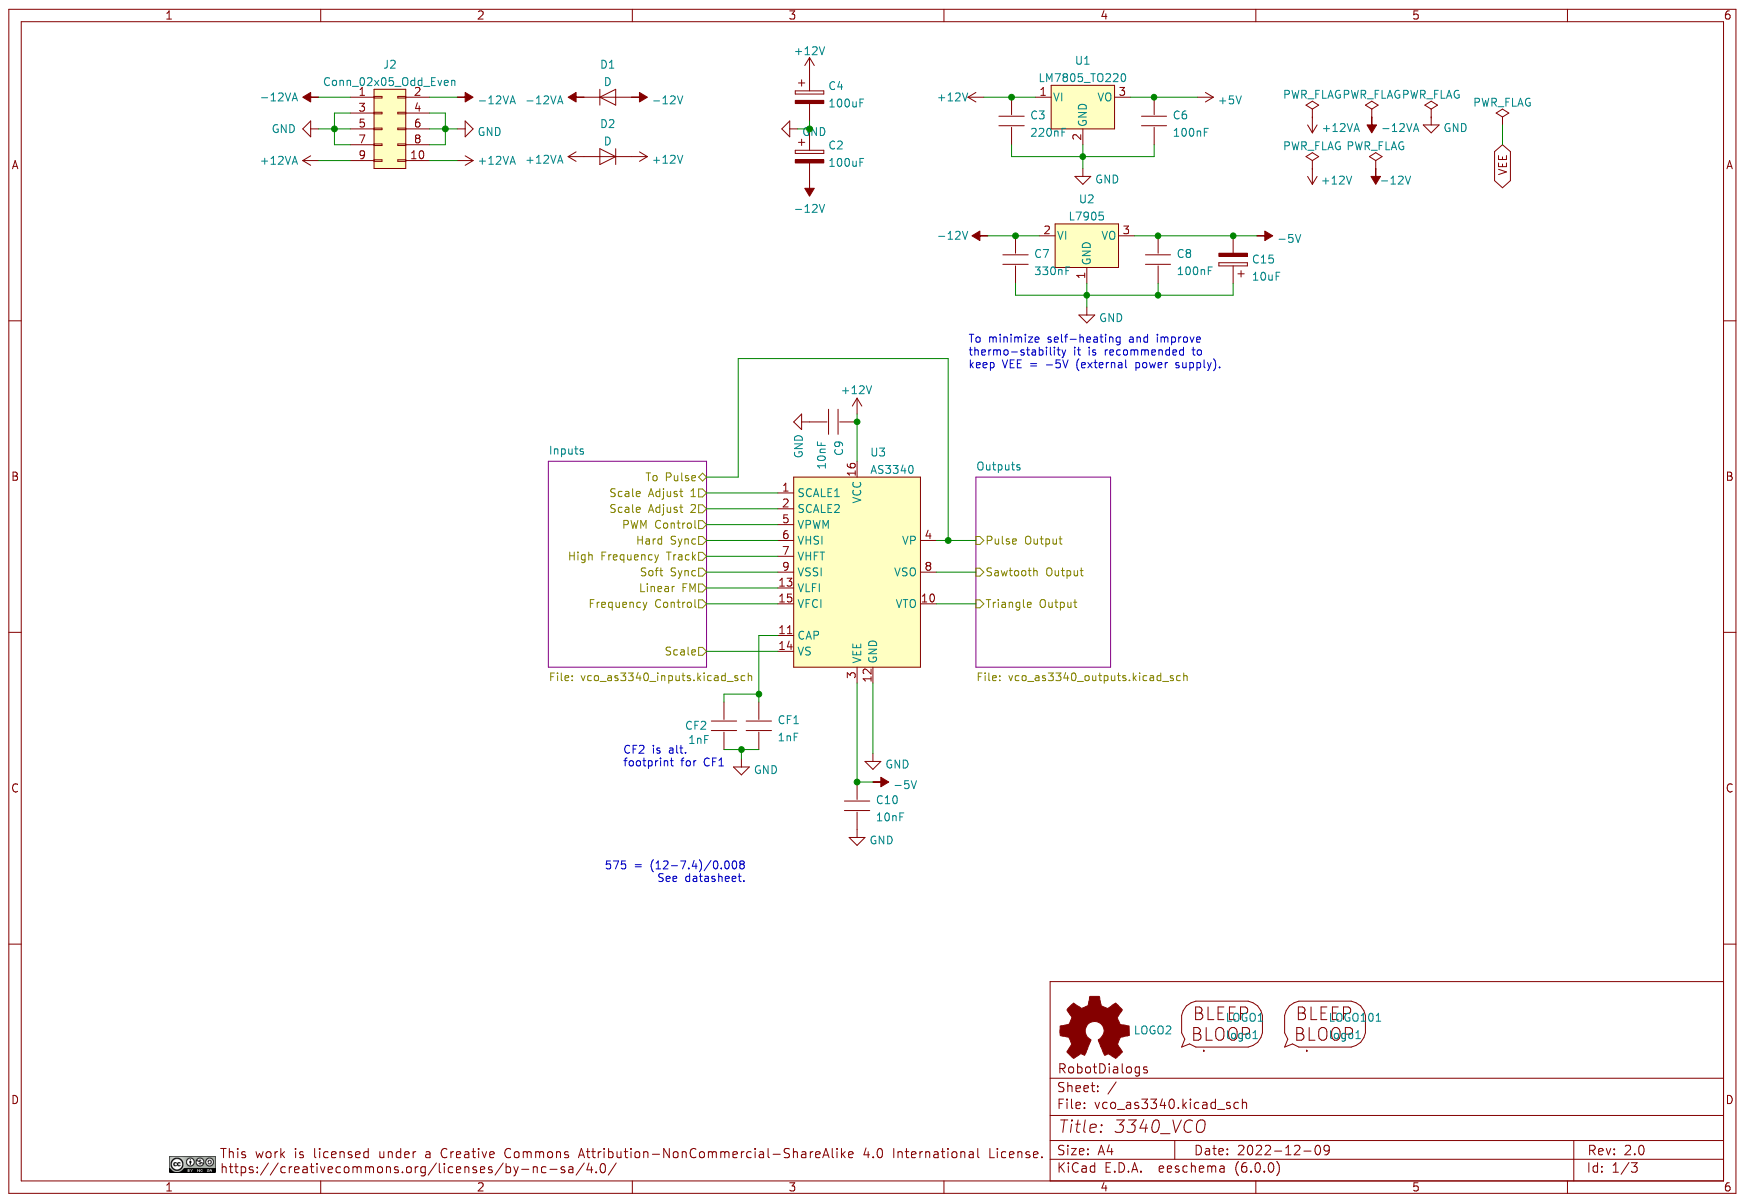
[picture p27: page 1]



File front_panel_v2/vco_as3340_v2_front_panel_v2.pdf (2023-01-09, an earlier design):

1








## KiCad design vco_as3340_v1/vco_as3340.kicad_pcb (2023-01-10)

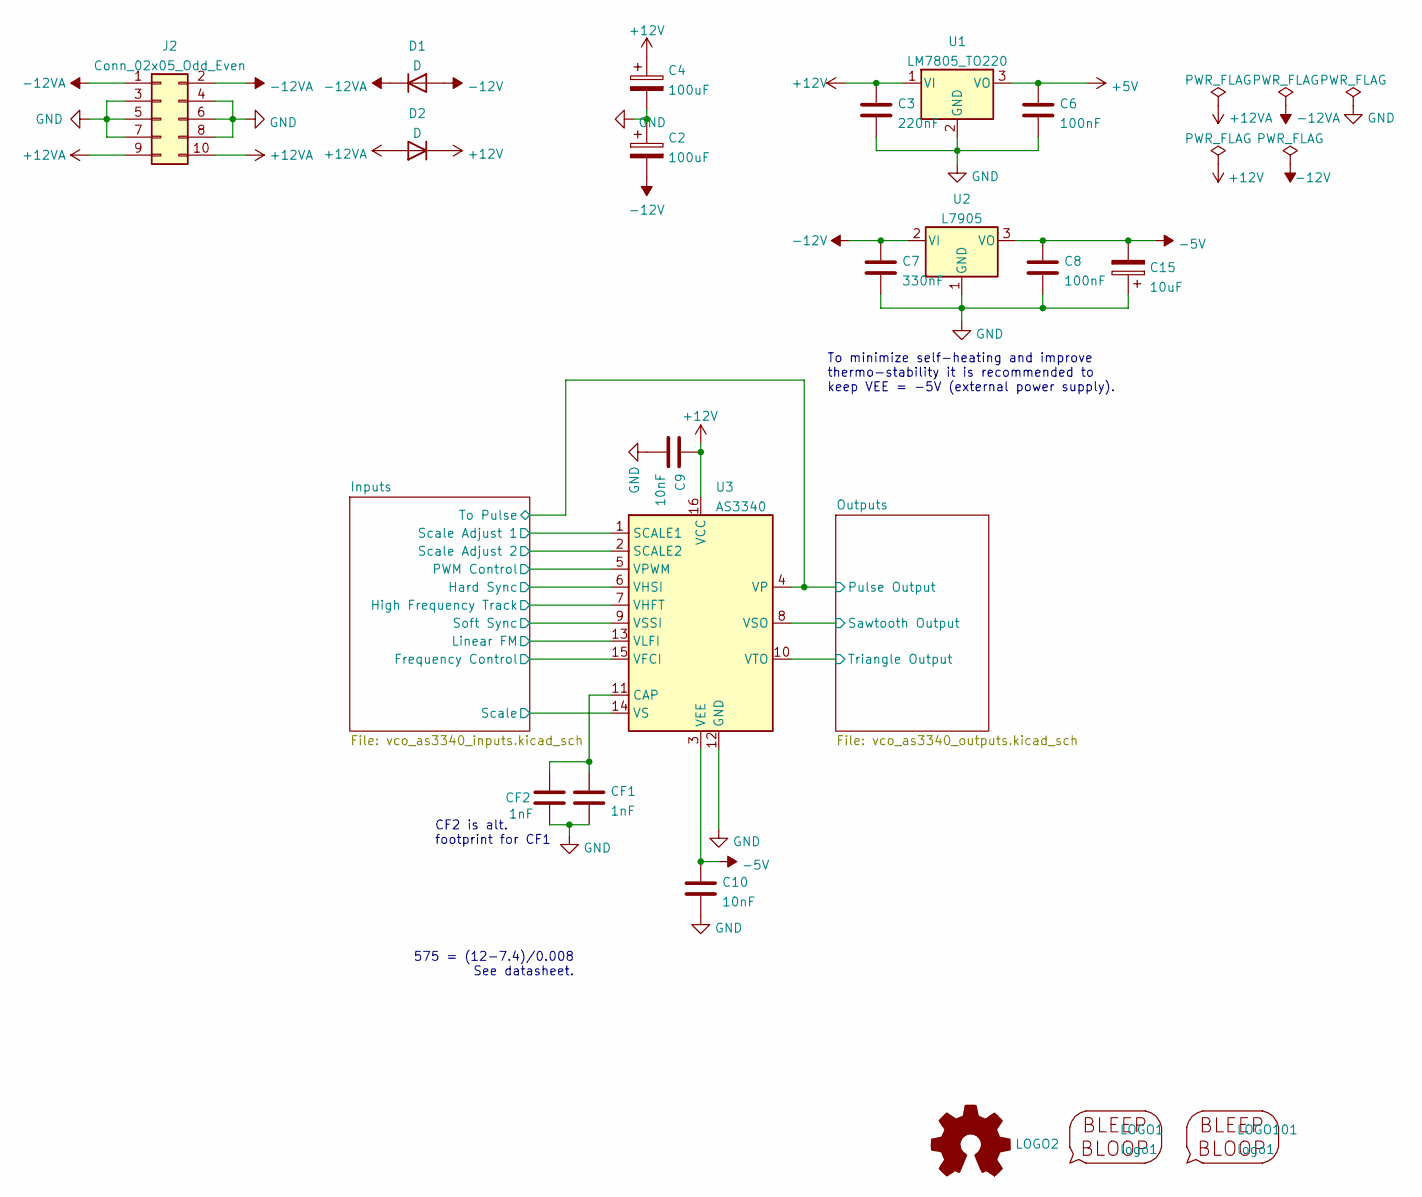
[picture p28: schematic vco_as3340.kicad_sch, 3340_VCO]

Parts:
C2, C4: 100uF; CP_Radial_D5.0mm_P2.50mm
C3: 220nF; C_1206_3216Metric_Pad1.33x1.80mm_HandSolder
C6, C8: 100nF; C_1206_3216Metric_Pad1.33x1.80mm_HandSolder
C7: 330nF; C_1206_3216Metric_Pad1.33x1.80mm_HandSolder
C9, C10: 10nF; C_1206_3216Metric_Pad1.33x1.80mm_HandSolder
C15: 10uF; CP_Radial_D5.0mm_P2.50mm
CF1: 1nF; C_Rect_L10.0mm_W2.5mm_P7.50mm_MKS4
CF2: 1nF; C_Rect_L7.0mm_W2.5mm_P5.00mm
D1, D2: D; D_A-405_P2.54mm_Vertical_KathodeUp
J2: Conn_02x05_Odd_Even; IDC-Header_2x05_P2.54mm_Vertical
LOGO1: logo1; Logo1
LOGO2: Logo_Open_Hardware_Small; OSHW-Symbol_6.7x6mm_SilkScreen
LOGO101: logo1; Logo2
U1: LM7805_TO220; TO-220-3_Vertical
U2: L7905; TO-220-3_Vertical
U3: AS3340; DIP-16_W7.62mm_Socket_LongPads

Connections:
+5V: C6.1, U1.3 (VO); also elsewhere on the board
+12V: C3.1, C4.1, C9.1, D2.1 (K), U1.1 (VI), U3.16 (VCC); also elsewhere on the board
+12VA: D2.2 (A), J2.9, J2.10
-5V: C8.1, C10.1, C15.2, U2.3 (VO), U3.3 (VEE); also elsewhere on the board
-12V: C2.2, C7.1, D1.2 (A), U2.2 (VI); also elsewhere on the board
-12VA: D1.1 (K), J2.1, J2.2
/Inputs/Frequency Control: U3.15 (VFCI); also elsewhere on the board
/Inputs/Hard Sync: U3.6 (VHSI); also elsewhere on the board
/Inputs/High Frequency Track: U3.7 (VHFT); also elsewhere on the board
/Inputs/Linear FM: U3.13 (VLFI); also elsewhere on the board
/Inputs/PWM Control: U3.5 (VPWM); also elsewhere on the board
/Inputs/Scale: U3.14 (VS); also elsewhere on the board
/Inputs/Scale Adjust 1: U3.1 (SCALE1); also elsewhere on the board
/Inputs/Scale Adjust 2: U3.2 (SCALE2); also elsewhere on the board
/Inputs/Soft Sync: U3.9 (VSSI); also elsewhere on the board
/Inputs/To Pulse: U3.4 (VP); also elsewhere on the board
/Outputs/Sawtooth Output: U3.8 (VSO); also elsewhere on the board
/Outputs/Triangle Output: U3.10 (VTO); also elsewhere on the board
GND: C2.1, C3.2, C4.2, C6.2, C7.2, C8.2, C9.2, C10.2, C15.1, CF1.2, CF2.2, J2.3, J2.4, J2.5, J2.6, J2.7, J2.8, U1.2 (GND), U2.1 (GND), U3.12 (GND); also elsewhere on the board
unnamed: CF1.1, CF2.1, U3.11 (CAP)

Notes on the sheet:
575 = (12-7.4)/0.008 See datasheet.
To minimize self-heating and improve thermo-stability it is recommended to keep VEE = -5V (external power supply).
CF2 is alt. footprint for CF1

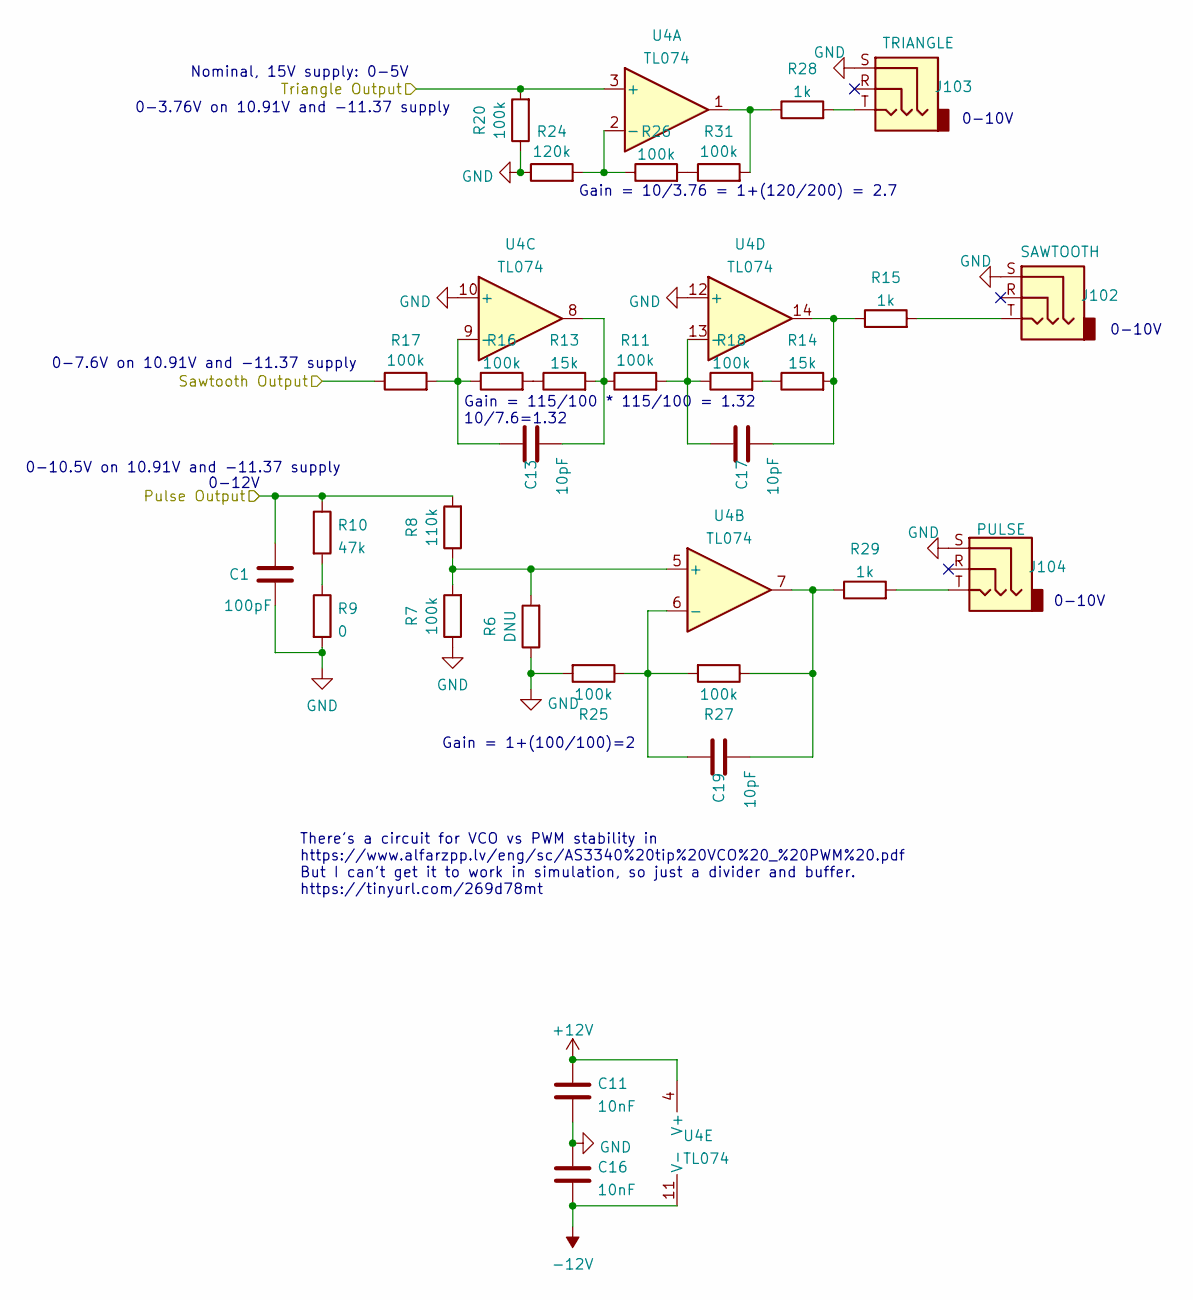
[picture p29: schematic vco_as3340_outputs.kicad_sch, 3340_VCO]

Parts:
C1: 100pF; C_1206_3216Metric_Pad1.33x1.80mm_HandSolder
C11, C16: 10nF; C_1206_3216Metric_Pad1.33x1.80mm_HandSolder
C13, C17, C19: 10pF; C_1206_3216Metric_Pad1.33x1.80mm_HandSolder
J102: SAWTOOTH; Jack_3.5mm_MJ-355W_Vertical
J103: TRIANGLE; Jack_3.5mm_MJ-355W_Vertical
J104: PULSE; Jack_3.5mm_MJ-355W_Vertical
R6: DNU; R_1206_3216Metric_Pad1.30x1.75mm_HandSolder
R7, R11, R16, R17, R18, R20, R25, R26, R27, R31: 100k; R_1206_3216Metric_Pad1.30x1.75mm_HandSolder
R8: 110k; R_1206_3216Metric_Pad1.30x1.75mm_HandSolder
R9: 0; R_1206_3216Metric_Pad1.30x1.75mm_HandSolder
R10: 47k; R_1206_3216Metric_Pad1.30x1.75mm_HandSolder
R13, R14: 15k; R_1206_3216Metric_Pad1.30x1.75mm_HandSolder
R15, R28, R29: 1k; R_1206_3216Metric_Pad1.30x1.75mm_HandSolder
R24: 120k; R_1206_3216Metric_Pad1.30x1.75mm_HandSolder
U4: TL074; DIP-14_W7.62mm_Socket_LongPads

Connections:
+12V: C11.1, U4.4 (V+); also elsewhere on the board
-12V: C16.2, U4.11 (V-); also elsewhere on the board
/Inputs/To Pulse: C1.1, R8.2, R10.1; also elsewhere on the board
/Outputs/Sawtooth Output: R17.1; also elsewhere on the board
/Outputs/Triangle Output: R20.2, U4.3 (+); also elsewhere on the board
GND: C1.2, C11.2, C16.1, J102.S, J103.S, J104.S, R6.1, R7.1, R9.2, R20.1, R24.1, R25.2, U4.10 (+), U4.12 (+); also elsewhere on the board
unnamed: C13.1, R16.1, R17.2, U4.9 (-)
unnamed: C13.2, R11.1, R13.2, U4.8
unnamed: C17.1, R11.2, R18.1, U4.13 (-)
unnamed: C17.2, R14.2, R15.1, U4.14
unnamed: C19.1, R25.1, R27.2, U4.6 (-)
unnamed: C19.2, R27.1, R29.1, U4.7
unnamed: J102.T, R15.2
unnamed: J103.T, R28.2
unnamed: J104.T, R29.2
unnamed: R6.2, R7.2, R8.1, U4.5 (+)
unnamed: R9.1, R10.2
unnamed: R13.1, R16.2
unnamed: R14.1, R18.2
unnamed: R24.2, R26.1, U4.2 (-)
unnamed: R26.2, R31.1
unnamed: R28.1, R31.2, U4.1

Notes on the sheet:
0-10.5V on 10.91V and -11.37 supply
0-10V
Gain = 1+(100/100)=2
0-12V
0-7.6V on 10.91V and -11.37 supply
There's a circuit for VCO vs PWM stability in https://www.alfarzpp.lv/eng/sc/AS3340%20tip%20VCO%20_%20PWM%20.pdf But I can't get it to work in simulation, so just a divider and buffer. https://tinyurl.com/269d78mt
Gain = 10/3.76 = 1+(120/200) = 2.7
Gain = 115/100 * 115/100 = 1.32 10/7.6=1.32
Nominal, 15V supply: 0-5V
0-3.76V on 10.91V and -11.37 supply

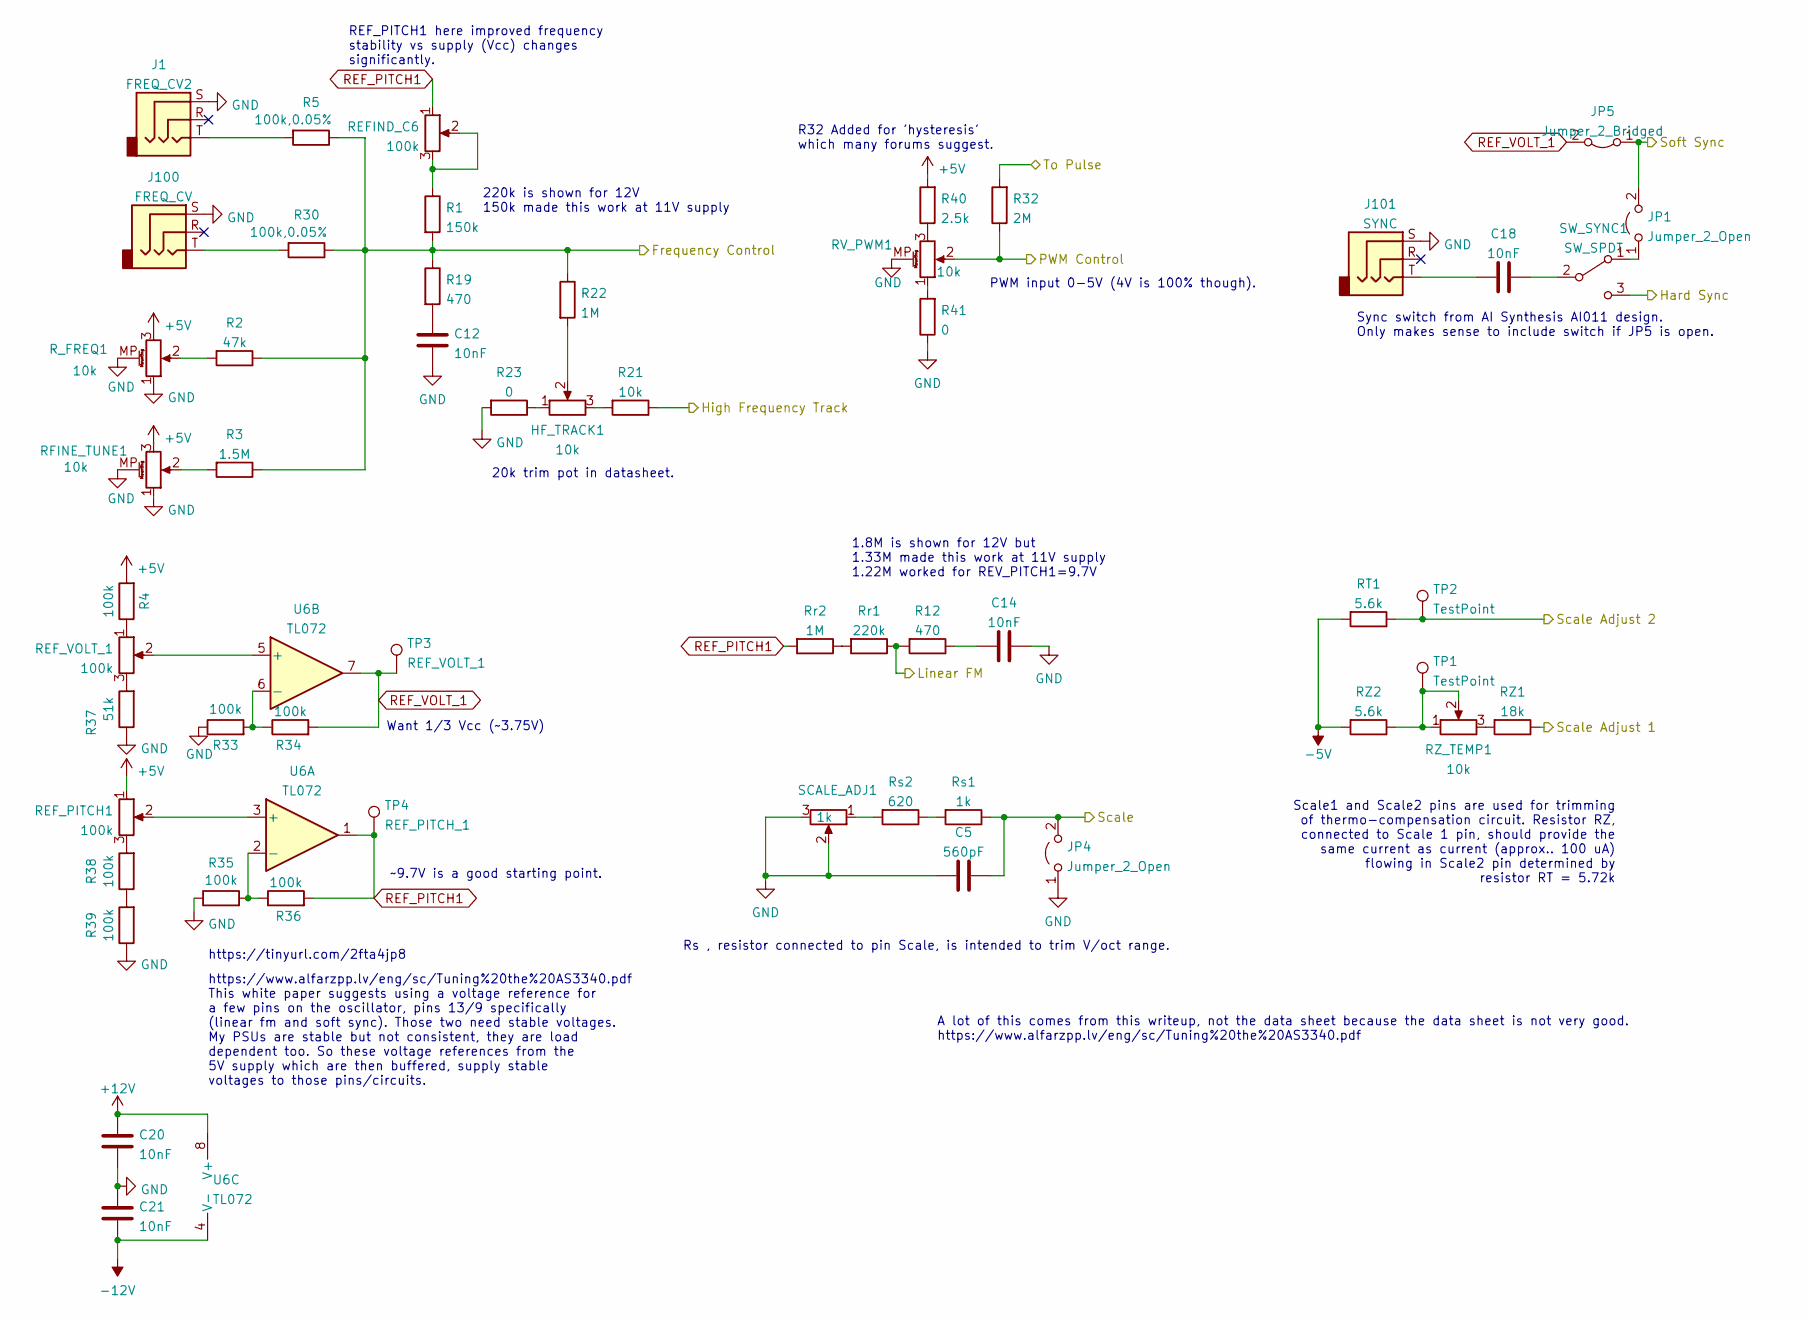
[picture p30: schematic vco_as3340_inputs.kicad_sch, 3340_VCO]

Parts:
C5: 560pF; C_1206_3216Metric_Pad1.33x1.80mm_HandSolder
C12, C14, C18, C20, C21: 10nF; C_1206_3216Metric_Pad1.33x1.80mm_HandSolder
HF_TRACK1: 10k; Potentiometer_Bourns_3296W_Vertical
J1: FREQ_CV2; Jack_3.5mm_MJ-355W_Vertical
J100: FREQ_CV; Jack_3.5mm_MJ-355W_Vertical
J101: SYNC; Jack_3.5mm_MJ-355W_Vertical
JP1: Jumper_2_Open; SolderJumper-2_P1.3mm_Open_Pad1.0x1.5mm
JP4: Jumper_2_Open; PinHeader_1x02_P2.54mm_Vertical
JP5: Jumper_2_Bridged; SolderJumper-2_P1.3mm_Bridged_Pad1.0x1.5mm
R1: 150k; R_1206_3216Metric_Pad1.30x1.75mm_HandSolder
R2: 47k; R_1206_3216Metric_Pad1.30x1.75mm_HandSolder
R3: 1.5M; R_1206_3216Metric_Pad1.30x1.75mm_HandSolder
R4, R33, R34, R35, R36, R38, R39: 100k; R_1206_3216Metric_Pad1.30x1.75mm_HandSolder
R5, R30: 100k,0.05%; R_1206_3216Metric_Pad1.30x1.75mm_HandSolder
R12, R19: 470; R_1206_3216Metric_Pad1.30x1.75mm_HandSolder
R21: 10k; R_1206_3216Metric_Pad1.30x1.75mm_HandSolder
R22: 1M; R_1206_3216Metric_Pad1.30x1.75mm_HandSolder
R23, R41: 0; R_1206_3216Metric_Pad1.30x1.75mm_HandSolder
R32: 2M; R_1206_3216Metric_Pad1.30x1.75mm_HandSolder
R37: 51k; R_1206_3216Metric_Pad1.30x1.75mm_HandSolder
R40: 2.5k; R_1206_3216Metric_Pad1.30x1.75mm_HandSolder
REFIND_C6: 100k; Potentiometer_Bourns_3296W_Vertical
REF_PITCH1: 100k; Potentiometer_Bourns_3296W_Vertical
REF_VOLT_1: 100k; Potentiometer_Bourns_3296W_Vertical
RFINE_TUNE1: 10k; Potentiometer_Alpha_RD901F-40-00D_Single_Vertical_w_3d
RT1: 5.6k; R_1206_3216Metric_Pad1.30x1.75mm_HandSolder
RV_PWM1: 10k; Potentiometer_Alpha_RD901F-40-00D_Single_Vertical_w_3d
RZ1: 18k; R_1206_3216Metric_Pad1.30x1.75mm_HandSolder
RZ2: 5.6k; R_1206_3216Metric_Pad1.30x1.75mm_HandSolder
RZ_TEMP1: 10k; Potentiometer_Bourns_3296W_Vertical
R_FREQ1: 10k; Potentiometer_Alpha_RD901F-40-00D_Single_Vertical_w_3d
Rr1: 220k; R_1206_3216Metric_Pad1.30x1.75mm_HandSolder
Rr2: 1M; R_1206_3216Metric_Pad1.30x1.75mm_HandSolder
Rs1: 1k; R_1206_3216Metric_Pad1.30x1.75mm_HandSolder
Rs2: 620; R_1206_3216Metric_Pad1.30x1.75mm_HandSolder
SCALE_ADJ1: 1k; Potentiometer_Bourns_3296W_Vertical
SW_SYNC1: SW_SPDT; SPDT_Toggle
TP1, TP2: TestPoint; PinHeader_1x01_P2.54mm_Vertical
TP3: REF_VOLT_1; PinHeader_1x01_P2.54mm_Vertical
TP4: REF_PITCH_1; PinHeader_1x01_P2.54mm_Vertical
U6: TL072; DIP-8_W7.62mm_Socket_LongPads

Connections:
+5V: R4.2, R40.2, REF_PITCH1.1, RFINE_TUNE1.3, R_FREQ1.3; also elsewhere on the board
+12V: C20.1, U6.8 (V+); also elsewhere on the board
-5V: RT1.2, RZ2.2; also elsewhere on the board
-12V: C21.2, U6.4 (V-); also elsewhere on the board
/Inputs/Frequency Control: R1.2, R2.1, R3.1, R5.1, R19.1, R22.1, R30.1; also elsewhere on the board
/Inputs/Hard Sync: SW_SYNC1.3 (C); also elsewhere on the board
/Inputs/High Frequency Track: R21.1; also elsewhere on the board
/Inputs/Linear FM: R12.2, Rr1.1; also elsewhere on the board
/Inputs/PWM Control: R32.1, RV_PWM1.2; also elsewhere on the board
/Inputs/Scale: C5.2, JP4.2 (B), Rs1.1; also elsewhere on the board
/Inputs/Scale Adjust 1: RZ1.1; also elsewhere on the board
/Inputs/Scale Adjust 2: RT1.1, TP2.1; also elsewhere on the board
/Inputs/Soft Sync: JP1.2 (B), JP5.1 (A); also elsewhere on the board
/Inputs/To Pulse: R32.2; also elsewhere on the board
GND: C5.1, C12.1, C14.2, C20.2, C21.1, J1.S, J100.S, J101.S, JP4.1 (A), R23.2, R33.1, R35.1, R37.1, R39.1, R41.1, RFINE_TUNE1.1, RFINE_TUNE1.MP (MountPin), RV_PWM1.MP (MountPin), R_FREQ1.1, R_FREQ1.MP (MountPin), SCALE_ADJ1.2, SCALE_ADJ1.3; also elsewhere on the board
unnamed: C12.2, R19.2
unnamed: C14.1, R12.1
unnamed: C18.1, J101.T
unnamed: C18.2, SW_SYNC1.2 (B)
unnamed: HF_TRACK1.1, R23.1
unnamed: HF_TRACK1.2, R22.2
unnamed: HF_TRACK1.3, R21.2
unnamed: J1.T, R5.2
unnamed: J100.T, R30.2
unnamed: R1.1, REFIND_C6.2, REFIND_C6.3
unnamed: R2.2, R_FREQ1.2
unnamed: R3.2, RFINE_TUNE1.2
unnamed: R4.1, REF_VOLT_1.1
unnamed: R33.2, R34.1, U6.6 (-)
unnamed: R35.2, R36.1, U6.2 (-)
unnamed: R37.2, REF_VOLT_1.3
unnamed: R38.1, R39.2
unnamed: R38.2, REF_PITCH1.3
unnamed: R40.1, RV_PWM1.3
unnamed: R41.2, RV_PWM1.1
unnamed: REF_PITCH1.2, U6.3 (+)
unnamed: REF_VOLT_1.2, U6.5 (+)
unnamed: RZ1.2, RZ_TEMP1.3
unnamed: RZ2.1, RZ_TEMP1.1, RZ_TEMP1.2, TP1.1
unnamed: Rr1.2, Rr2.1
unnamed: Rs1.2, Rs2.1
unnamed: Rs2.2, SCALE_ADJ1.1
unnamed: JP1.1 (A), SW_SYNC1.1 (A)
REF_PITCH1: R36.2, REFIND_C6.1, Rr2.2, TP4.1, U6.1
REF_VOLT_1: JP5.2 (B), R34.2, TP3.1, U6.7

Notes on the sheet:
R32 Added for 'hysteresis' which many forums suggest.
Scale1 and Scale2 pins are used for trimming of thermo-compensation circuit. Resistor RZ, connected to Scale 1 pin, should provide the same current as current (approx.. 100 uA) flowing in Scale2 pin determined by resistor RT = 5.72k
PWM input 0-5V (4V is 100% though).
220k is shown for 12V 150k made this work at 11V supply
REF_PITCH1 here improved frequency stability vs supply (Vcc) changes significantly.
~9.7V is a good starting point.
https://www.alfarzpp.lv/eng/sc/Tuning%20the%20AS3340.pdf This white paper suggests using a voltage reference for a few pins on the oscillator, pins 13/9 specifically (linear fm and soft sync). Those two need stable voltages. My PSUs are stable but not consistent, they are load dependent too. So the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
Sync switch from AI Synthesis AI011 design. Only makes sense to include switch if JP5 is open.
20k trim pot in datasheet.
Rs , resistor connected to pin Scale, is intended to trim V/oct range.
https://tinyurl.com/2fta4jp8
1.8M is shown for 12V but 1.33M made this work at 11V supply 1.22M worked for REV_PITCH1=9.7V
Want 1/3 Vcc (~3.75V)
A lot of this comes from this writeup, not the data sheet because the data sheet is not very good. https://www.alfarzpp.lv/eng/sc/Tuning%20the%20AS3340.pdf

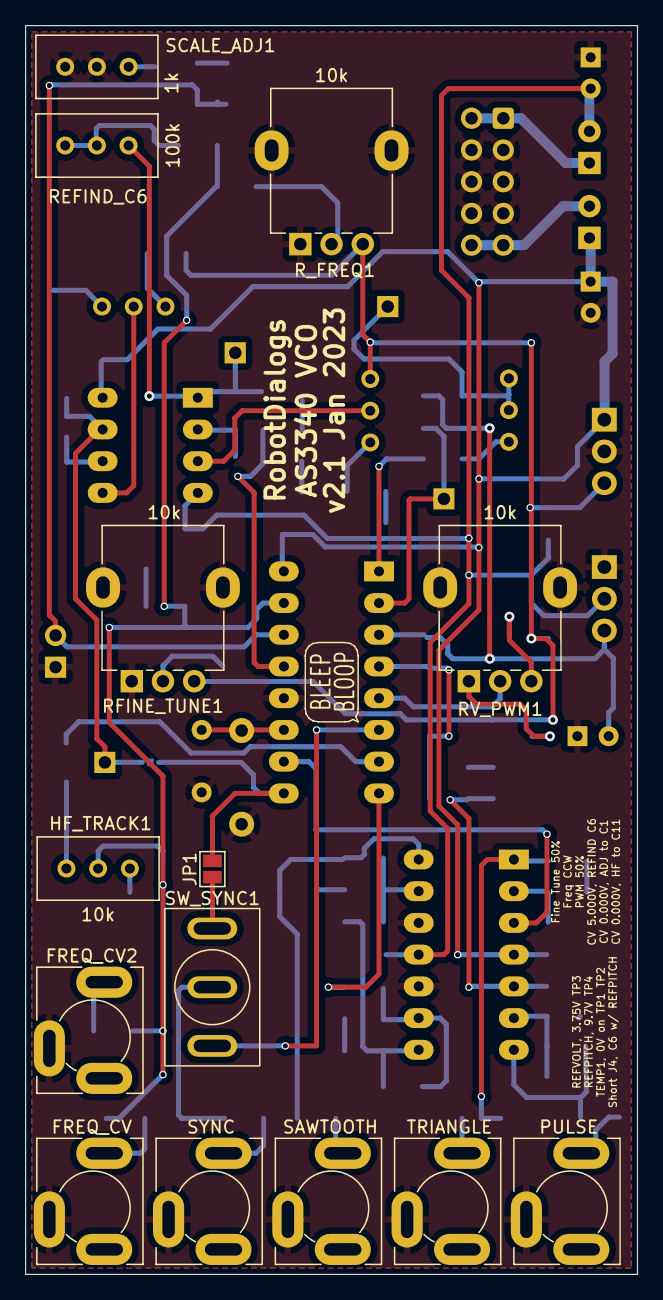
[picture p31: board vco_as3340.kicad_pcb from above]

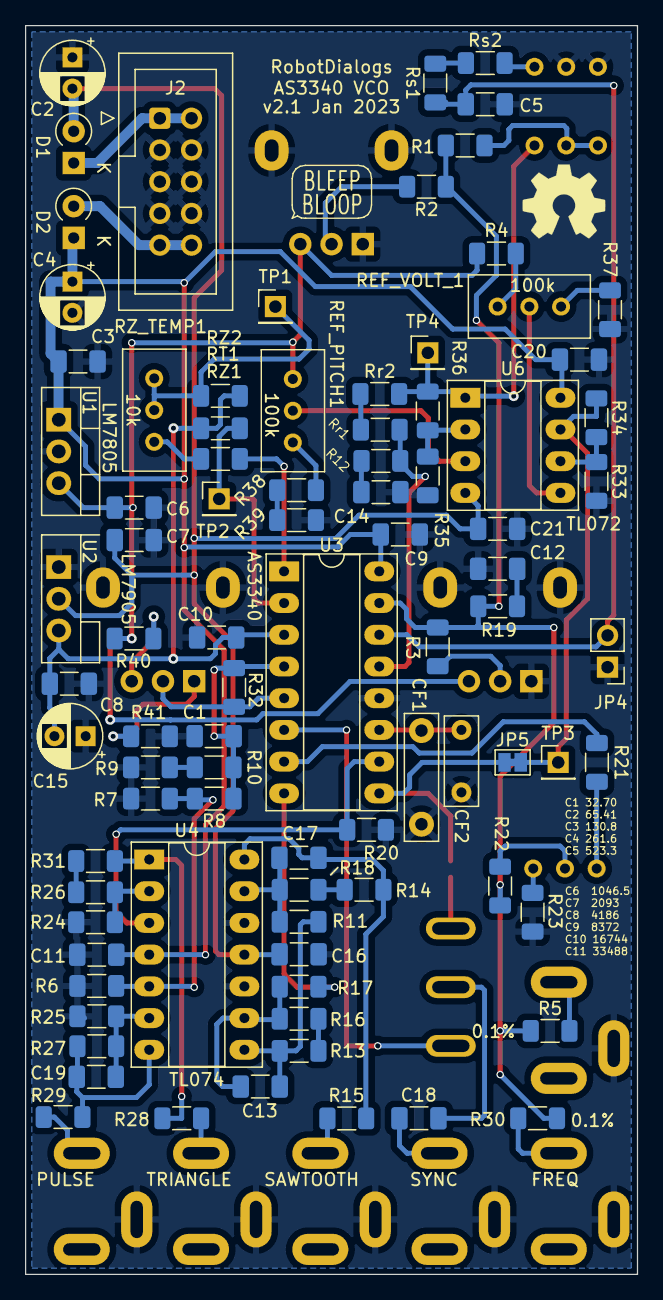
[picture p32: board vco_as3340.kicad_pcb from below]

Board: 2 copper layers, 49.0 x 100.0 mm, 105 parts (89 on the bottom side), 66 nets.

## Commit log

2022-07-02 First pass at a schematic, untested.
    https://www.alfarzpp.lv/eng/sc/AS3340.pdf
    https://www.alfarzpp.lv/eng/sc/Tuning%20the%20AS3340.pdf
    [vco_as3340_inputs.kicad_sch, vco_as3340_outputs.kicad_sch, vco_as3340_v1.kicad_pcb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]
2022-07-03 Schematic update from breadboarding, start layout
    [vco_as3340_inputs.kicad_sch, vco_as3340_outputs.kicad_sch, vco_as3340_v1.kicad_pcb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]
2022-07-04 Layout and routing done
    [vco_as3340_inputs.kicad_sch, vco_as3340_v1.kicad_pcb, vco_as3340_v1.kicad_sch]
2022-07-04 Geographic re-annotate and cleanup
    [vco_as3340_inputs.kicad_sch, vco_as3340_outputs.kicad_sch, vco_as3340_v1.kicad_pcb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]
2022-07-07 Grid origin update
    [vco_as3340_v1.kicad_pcb]
2022-07-27 Panelized v1 and bom
    [vco_as3340_v1_panelized.kicad_pcb]
2022-07-27 Front Panel v1 CAD
    [vco_as3340_front_panel_v1.FCStd, vco_as3340_front_panel_v1_engraving.dxf, vco_as3340_front_panel_v1_no_engraving.dxf]
2022-07-27 Front Panel v1.1
    Moved engraved text around
    [vco_as3340_front_panel_engraving_v1.1.dxf, vco_as3340_front_panel_v1.1.FCStd]
2022-10-16 Schematic Changes v1 to v2
    - R10 = 47k
    - R9 = 0ohm
    - New C1 100pF across R10 and R9
    - New C15 10uF polarized cap from -5 to GND.
    - R6 DNU
    - R21 & R23 changed to 5.1k
    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
    [vco_as3340_inputs.kicad_sch, vco_as3340_outputs.kicad_sch, vco_as3340_v1.kicad_sch]
2022-12-09 v2 re-layout pcb
    [vco_as3340_inputs.kicad_sch, vco_as3340_outputs.kicad_sch, vco_as3340_v1.kicad_pcb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]
2022-12-10 Routing done
    [vco_as3340_inputs.kicad_sch, vco_as3340_v1.kicad_pcb, vco_as3340_v1.kicad_sch]
2022-12-17 v2 panelized
    [vco_as3340_v1.kicad_pcb, vco_as3340_v2_panelized.kicad_pcb]
2022-12-17 Rename kicad project
    [vco_as3340.kicad_pcb, vco_as3340.kicad_sch]
2023-01-09 Add Front Panel v2 docs
    [vco_as3340_v2_front_panel_v2.FCStd, vco_as3340_v2_front_panel_v2_engraving.dxf, vco_as3340_v2_front_panel_v2_no_engraving.dxf]
2023-01-10 Changes to v2 from testing
    [vco_as3340.kicad_pcb, vco_as3340.kicad_sch, vco_as3340_inputs.kicad_sch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]
2023-01-10 v2.1 panelized
    [vco_as3340_v2_1_panelized.kicad_pcb]
2023-01-19 Add v2.1 schematic pdf
    Adjusted R40 to be 2.4k instead of 2.5k which isn't an E24 value.
    [vco_as3340.kicad_sch, vco_as3340_inputs.kicad_sch]
2023-01-19 Front Panel v2.1
    Removed trim pot holes that were in the wrong place and not labeled,
    don't really need them.
    Removed the SYNC switch, see schematic notes on v2 & v2.1, it doesn't
    add much.
    [vco_as3340_v2.1_front_panel_v2.1.FCStd, vco_as3340_v2.1_front_panel_v2.1_engraving.dxf, vco_as3340_v2.1_front_panel_v2.1_no_engraving.dxf]
